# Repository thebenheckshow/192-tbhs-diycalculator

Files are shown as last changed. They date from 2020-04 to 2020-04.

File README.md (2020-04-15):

# 192-tbhs-diycalculator
Ben, Felix and Max take us back to 1972 and the invention of the first calculator this week, then decide to hack their own! Watch as they use the Raspberry Pi Compute Module and a Formlabs SLA 3D printer to create their own graphing calculator.

https://www.element14.com/community/docs/DOC-77309/l/episode-192-ben-hecks-diy-calculator-episode

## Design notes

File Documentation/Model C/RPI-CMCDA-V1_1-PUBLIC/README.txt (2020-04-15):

Copyright (c) 2014 Raspberry Pi (Trading) Ltd. All rights reserved.

Redistribution and use in source and binary forms, with or without 
modification, are permitted provided that the following conditions 
are met:

- Redistributions of source code must retain the above copyright notice,
  this list of conditions and the following disclaimer.

- Redistributions in binary form must reproduce the above copyright
  notice, this list of conditions and the following disclaimer in the 
  documentation and/or other materials provided with the distribution.

- Neither the name of the Raspberry Pi Foundation, nor 
  Raspberry Pi (Trading) Ltd, nor the names of its contributors may be
  used to endorse or promote products derived from this product without
  specific prior written permission.

THIS PRODUCT IS PROVIDED BY THE COPYRIGHT HOLDERS AND CONTRIBUTORS 
"AS IS" AND ANY EXPRESS OR IMPLIED WARRANTIES, INCLUDING, BUT NOT 
LIMITED TO, THE IMPLIED WARRANTIES OF MERCHANTABILITY AND FITNESS FOR A
PARTICULAR PURPOSE ARE DISCLAIMED. IN NO EVENT SHALL
RASPBERRY PI (TRADING) LTD BE LIABLE FOR ANY DIRECT, INDIRECT,
INCIDENTAL, SPECIAL, EXEMPLARY, OR CONSEQUENTIAL DAMAGES (INCLUDING,
BUT NOT LIMITED TO, PROCUREMENT OF SUBSTITUTE GOODS OR SERVICES; LOSS
OF USE, DATA, OR PROFITS; OR BUSINESS INTERRUPTION) HOWEVER CAUSED AND
ON ANY THEORY OF LIABILITY, WHETHER IN CONTRACT, STRICT LIABILITY, OR
TORT (INCLUDING NEGLIGENCE OR OTHERWISE) ARISING IN ANY WAY OUT OF THE
USE OF THIS PRODUCT, EVEN IF ADVISED OF THE POSSIBILITY OF SUCH DAMAGE.

This zip file should contain:
  README.txt (this file)
  RPI-CMCDA-V1_1-PUBLIC.DSN (Cadence OrCAD Schematic)
  RPI-CMCDA-V1_1-PUBLIC.brd (Cadence OrCAD/Allegro PCB file)
  RPI-CMCDA-V1_1-PUBLIC-BOM.xlsx (Bill of Materials)
  RPI-CMCDA-V1_1-PUBLIC-SCHEMATIC.pdf (PDF of schematic)
  /GERBERS (Board gerbers, see README.txt in this directory for further info)

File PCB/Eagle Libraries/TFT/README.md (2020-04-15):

Included parts:
---------------

* 7499210124A - Ethernet Jack / LAN-Transformer WE-RJ45LAN 10/100BaseT PoE
  * Datasheet: http://katalog.we-online.de/pbs/datasheet/7499210124A.pdf
* MFCR531 - Standard ISO/IEC 14443 A/B reader solution
  * Datasheet: http://www.nxp.com/documents/data_sheet/MFRC531.pdf
* MI0283QT-11 - 2.8" LCD Module
  * Datasheet: http://www.watterott.com/media/files_public/qwpedbempo/MI0283QT-11_Datasheet.PDF
* STM809 - Reset circuit
  * Datasheet: http://www.st.com/web/en/resource/technical/document/datasheet/CD00003591.pdf
* TL2575 - 1-A SIMPLE STEP-DOWN SWITCHING VOLTAGE REGULATORS
  * Datasheet: http://www.ti.com/lit/ds/symlink/tl2575-05.pdf
* TSC2046 - Low-Voltage I/O TOUCH SCREEN CONTROLLER
  * Datasheet: http://www.ti.com/lit/ds/symlink/tsc2046.pdf

Warranty
--------

Although these Parts are proven in production, there is no warranty that these libraries will fit to your parts. 
So be careful and always recheck them if you use them in your design.

Licence
-------

<br />This work is licensed under a <a rel="license" href="http://creativecommons.org/licenses/by-sa/4.0/">Creative Commons Attribution-ShareAlike 4.0 International License</a>.

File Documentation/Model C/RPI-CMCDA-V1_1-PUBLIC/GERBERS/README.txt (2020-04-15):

Copyright (c) 2014 Raspberry Pi (Trading) Ltd. All rights reserved.

Redistribution and use in source and binary forms, with or without 
modification, are permitted provided that the following conditions 
are met:

- Redistributions of source code must retain the above copyright notice,
  this list of conditions and the following disclaimer.

- Redistributions in binary form must reproduce the above copyright
  notice, this list of conditions and the following disclaimer in the 
  documentation and/or other materials provided with the distribution.

- Neither the name of the Raspberry Pi Foundation, nor 
  Raspberry Pi (Trading) Ltd, nor the names of its contributors may be
  used to endorse or promote products derived from this product without
  specific prior written permission.

THIS PRODUCT IS PROVIDED BY THE COPYRIGHT HOLDERS AND CONTRIBUTORS 
"AS IS" AND ANY EXPRESS OR IMPLIED WARRANTIES, INCLUDING, BUT NOT 
LIMITED TO, THE IMPLIED WARRANTIES OF MERCHANTABILITY AND FITNESS FOR A
PARTICULAR PURPOSE ARE DISCLAIMED. IN NO EVENT SHALL
RASPBERRY PI (TRADING) LTD BE LIABLE FOR ANY DIRECT, INDIRECT,
INCIDENTAL, SPECIAL, EXEMPLARY, OR CONSEQUENTIAL DAMAGES (INCLUDING,
BUT NOT LIMITED TO, PROCUREMENT OF SUBSTITUTE GOODS OR SERVICES; LOSS
OF USE, DATA, OR PROFITS; OR BUSINESS INTERRUPTION) HOWEVER CAUSED AND
ON ANY THEORY OF LIABILITY, WHETHER IN CONTRACT, STRICT LIABILITY, OR
TORT (INCLUDING NEGLIGENCE OR OTHERWISE) ARISING IN ANY WAY OUT OF THE
USE OF THIS PRODUCT, EVEN IF ADVISED OF THE POSSIBILITY OF SUCH DAMAGE.

Name: Raspberry Pi Compute Module Camera / Display Adaptor
Date: 13/10/2014
Ref : RPI-CMCDA-V1_1-PUBLIC

Files:

  *-DRM.art         Manuf. Notes / Drill / Mechanical
  *-BRD.art         Board Edges
  *-TPM.art         Top Paste Mask
  *-TCL.art         Top Component Legend
  *-TSM.art         Top Solder Mask
  *-Lxx.art         Copper Layers (L01 = top layer)
  *-BSM.art         Bottom Solder Mask
  *-X-Y.drl         NC Drill layers X to Y (PLATED HOLES)
  *-TAS.pdf         Top Assembly Drawing
  *-IPC.ipc         IPC Netlist
  *-PLACE.txt       Component placement locations

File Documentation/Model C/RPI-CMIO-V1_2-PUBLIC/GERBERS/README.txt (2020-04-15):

Copyright (c) 2014 Raspberry Pi (Trading) Ltd. All rights reserved.

Redistribution and use in source and binary forms, with or without 
modification, are permitted provided that the following conditions 
are met:

- Redistributions of source code must retain the above copyright notice,
  this list of conditions and the following disclaimer.

- Redistributions in binary form must reproduce the above copyright
  notice, this list of conditions and the following disclaimer in the 
  documentation and/or other materials provided with the distribution.

- Neither the name of the Raspberry Pi Foundation, nor 
  Raspberry Pi (Trading) Ltd, nor the names of its contributors may be
  used to endorse or promote products derived from this product without
  specific prior written permission.

THIS PRODUCT IS PROVIDED BY THE COPYRIGHT HOLDERS AND CONTRIBUTORS 
"AS IS" AND ANY EXPRESS OR IMPLIED WARRANTIES, INCLUDING, BUT NOT 
LIMITED TO, THE IMPLIED WARRANTIES OF MERCHANTABILITY AND FITNESS FOR A
PARTICULAR PURPOSE ARE DISCLAIMED. IN NO EVENT SHALL
RASPBERRY PI (TRADING) LTD BE LIABLE FOR ANY DIRECT, INDIRECT,
INCIDENTAL, SPECIAL, EXEMPLARY, OR CONSEQUENTIAL DAMAGES (INCLUDING,
BUT NOT LIMITED TO, PROCUREMENT OF SUBSTITUTE GOODS OR SERVICES; LOSS
OF USE, DATA, OR PROFITS; OR BUSINESS INTERRUPTION) HOWEVER CAUSED AND
ON ANY THEORY OF LIABILITY, WHETHER IN CONTRACT, STRICT LIABILITY, OR
TORT (INCLUDING NEGLIGENCE OR OTHERWISE) ARISING IN ANY WAY OUT OF THE
USE OF THIS PRODUCT, EVEN IF ADVISED OF THE POSSIBILITY OF SUCH DAMAGE.

Name : Raspberry Pi Compute Module IO Board - PUBLIC RELEASE version
Date : 13/10/2014
Ref  : RPI-CMIO-V1_2-PUBLIC
Files:
  *-DRM.art     Manuf. Notes / Drill / Mechanical
  *-BRD.art     Board Edges
  *-TPM.art     Top Paste Mask
  *-TCL.art     Top Component Legend
  *-TSM.art     Top Solder Mask
  *-Lxx.art     Copper Layers (L01 = top layer)
  *-BSM.art     Bottom Solder Mask
  *-X-Y.drl     NC Drill layers X to Y (PLATED HOLES)
  *-X-Y-np.drl  NC Drill layers X to Y (NON PLATED HOLES)
  *-X-Y.rou     NC Route layers X to Y (PLATED ROUTES)
  *-TAS.pdf     Top Assembly Drawing
  *-BAS.pdf     Top Assembly Drawing
  *-IPC.ipc     IPC Netlist
  *-PLACE.txt   Component placement locations

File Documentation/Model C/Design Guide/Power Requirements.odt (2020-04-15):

COMPUTE MODULE HARDWARE DESIGN GUIDE

POWERING THE MODULE

The Compute Module has six separate supplies that must be present and powered at all times; you cannot leave any of them unpowered, even if a specific interface or GPIO bank is unused. The six supplies are as follows:

1. VBAT is used to power the BCM2835 processor core. It feeds the SMPS that generates the chip core voltage.

2. 3V3 powers various BCM2835 PHYs, IO and the eMMC Flash.

3. 1V8 powers various BCM2835 PHYs, IO and SDRAM.

4. VDAC powers the composite (TV-out) DAC.

5. GPIO0-27_VREF powers the GPIO 0-27 IO bank.

6. GPIO28-45_VREF powers the GPIO 28-45 IO bank.

GPIO28-45_VREF powers the GPIO 28-45 IO bank.

Supply | Voltage / Voltage Range | Tolerance
VBAT | 2.3-5V [1] | +/- 5%
3V3 | 3.3V | +/- 5%
1V8 | 1.8V | +/- 5%
VDAC | 2.5-2.8V (can connect to 3V3 if unused) | +/- 5%
GPIO0-27_VREF | 1.8-3.3V | +/- 5%
GPIO28-45_VREF | 1.8-3.3V | +/- 5%

[1] Note that the voltage range for best SMPS efficiency is ~3.3-4.3V.

POWER SEQUENCING

Supplies must be synchronised to come up at exactly the same time. Alternatively, they should be staggered so that the highest voltage comes up first, then the remaining voltages in descending order. This is to avoid forward biasing internal (on-chip) diodes between supplies, and causing latch-up.

POWER REQUIREMENTS

Exact power requirements will be heavily dependent upon the individual use case. If an on-chip subsystem is unused, it is usually in a low power state or completely turned off. For instance, if your application does not use 3D graphics then a large part of the core digital logic will never turn on and need power. This is also the case for camera and display interfaces, HDMI, USB interfaces, video encoders and decoders, and so on.

Powerchain design is critical for stable and reliable operation of the Compute Module. We strongly recommend that designers spend time measuring and verifying power requirements for their particular use case and application, as well as paying careful attention to power supply sequencing and maximum supply voltage tolerance.

The following table gives a rough guide to minimum supply requirements. However, the user is responsible for verifying that their powerchain is designed to be sufficient for their application. In some more unusual use cases these minimum requirements may well be too low!

Supply | Minimum Requirement (mA or mW)
VBAT | 2000mW [1]
3V3 | 250mA
1V8 | 250mA
VDAC | 25mA
GPIO0-27_VREF | 50mA [2]
GPIO28-45_VREF | 50mA [2]

[1] Note that VBAT is heavily dependent upon the application. For example, with video encoding, 3D and the camera all running the power requirements can be substantial.

[2] Note that each GPIO bank will only need a few mW if unused; however when in use, the requirements will vary depending on the number of IOs in use and the load on each. The maximum load per GPIO bank must not exceed 50mA.

MODULE BOOTING AND FLASHING THE EMMC

The 4GB eMMC Flash device on the Compute Module is directly connected to the primary BCM2835 SD/eMMC interface. These connections are not accessible on the module pins.

When initially powered on, or after the RUN pin has been held low and then released, the BCM2835 will try to access the eMMC device. It will then look for a file called bootcode.bin on the primary partition (which must be FAT) to start booting the system. If it cannot access the eMMC device or the boot code cannot be found, it will fall back to waiting for boot code to be written to it over USB; in other words, its USB port is in slave mode waiting to accept boot code from a suitable host.

A USB boot tool is available on github which allows a host PC running Linux to write the BCM2835 boot code over USB to the module. That boot code then runs and provides access to the eMMC as a USB mass storage device, which can then be read and written using the host PC. Note that a Raspberry Pi can be used as the host machine.

The Compute Module has a pin called EMMC_DISABLE_N which when shorted to GND will disable the eMMC, forcing BCM2835 to boot from USB. Note that when the eMMC is disabled in this way, it takes a few seconds from powering up for the processor to stop attempting to talk to the eMMC device and fall back to booting from USB.

Note that once booted over USB, BCM2835 needs to re-enable the eMMC device (by releasing EMMC_DISABLE_N) to allow access to it as mass storage. It expects to be able to do this by driving the GPIO47_1V8 pin LOW, which at boot is initially an input with a pull up to 1V8. If an end user wishes to add the ability to access the eMMC over USB in their product, similar circuitry to that used on the Compute Module IO Board to enable/disable the USB boot and eMMC must be used; that is, EMMC_DISABLE_N pulled low via MOSFET(s) and released again by MOSFET, with the gate controlled by GPIO47_1V8. Ensure you use MOSFETs suitable for switching at 1.8V (i.e. use a device with Vt << 1.8V).

For a step by step guide to flashing the eMMC please see: < http://www.raspberrypi.org/documentation/hardware/computemodule/cm-emmc-flashing.md >.

COMPUTE MODULE INTERFACES

GPIOS

Note that the GPIO46_1V8 and GPIO47_1V8 pins are 1.8V IO only and are reserved for special functions (HDMI hot plug detect and boot control respectively). Please don’t use these pins for any other purpose, as the software for the Compute Module will always expect these pins to have these special functions. If they are unused please leave them unconnected.

The remaining GPIOs are available for general use and are split into two banks. GPIO0 to GPIO27 are bank 0 and GPIO28-45 make up bank 1. GPIO0-27_VREF is the power supply for bank 0 and GPIO28-45_VREF is the power supply for bank 1. These supplies can be in the range 1.8V-3.3V. These supplies are not optional; each bank must be powered, even when none of the GPIOs for that bank are used.

All GPIOs except GPIO28, 29, 44 and 45 have weak in-pad pull-ups or pull-downs enabled when the device is powered on. Whether the GPIO is pulled up or down is documented in the BCM2835 peripherals document section 6.2. It is recommended to add off-chip pulls to GPIO28, 29, 44 and 45 to make sure they never float during power on and initial boot.

CSI (MIPI SERIAL CAMERA)

The Compute Module has two MIPI serial camera interfaces (CSI); Interface 0 and Interface 1.

Interface 0 is a 2-lane interface; one clock lane and two data lanes.

Interface 1 is a 4-lane interface; one clock lane and four data lanes.

Note that the Raspberry Pi Model A/B camera connector uses Interface 1, but only in a 2-lane configuration.

The camera interface(s) clock and data pins must be routed as matched length, matched phase 100 ohm differential PCB traces.

DSI (MIPI SERIAL DISPLAY)

The Compute Module has 2 MIPI serial display interfaces (DSI); Interface 0 and Interface 1.

Interface 0 is a 2-lane interface; one clock lane and two data lanes.

Interface 1 is a 4-lane interface; one clock lane and four data lanes.

Note that the Raspberry Pi Model A/B display connector uses Interface 1, but only in a 2-lane configuration.

The display interface(s) clock and data pins must be routed as matched length, matched phase 100 ohm differential PCB traces.

USB OTG

The BCM2835 USB port is On-The-Go (OTG) capable. If using either as a fixed slave or fixed master, please tie the USB_OTGID pin to ground.

The USB port (Pins USB_DP and USB_DM) must be routed as matched-phase 90 ohm differential PCB traces.

Note that the port is capable of being used as a true OTG port, but there is currently no documentation, code or examples for this use case.

HDMI

It is recommended that users follow a similar arrangement to the Compute Module IO Board circuitry for HDMI output.

The HDMI CK_P/N (clock) and D0-D2_P/N (data) pins must each be routed as matched length 100 ohm differential PCB traces. It is also important to make sure that each differential pair is closely phase matched.

Finally, keep HDMI traces well away from other noise sources and as short as possible.

Failure to observe these design rules is likely to result in EMC failure.

COMPOSITE (TVDAC)

The TVDAC pin can be used to output composite video. Please route this signal away from noise sources and use a 75 ohm PCB trace.

Note that the TV DAC is powered from the VDAC supply which must be a clean supply of 2.5-2.8V. It is recommended users generate this supply from 3V3 using a low noise LDO.

If the TVDAC output is not used VDAC can be connected to 3V3, but it must be powered even if the TV-out functionality is unused.

COMPUTE MODULE TEMPERATURE RANGE

The operating temperature range of the module is set by the lowest maximum and highest minimum of any of the components.

The Samsung eMMC and Samsung LPDDR2 are all rated for -25 to +80 degrees Celsius, so the range is -25 to +80. BCM2835 and the analogue switch have a greater range; the ceramic capacitors are specified from -25 to +85.

However, this range is the maximum for the silicon die; therefore, users would have to take into account the heat generated when in use and make sure this does not cause the temperature to exceed 80 degrees Celsius.

The user is responsible for designing and testing their system so that these limits are not exceeded.

COMPUTE MODULE FORM FACTOR

The Compute Module conforms to JEDEC MO-224 mechanical specification for 200 pin DDR2 (1.8V) SODIMM modules. Please note that the pinout of the Compute Module is not the same as a DDR2 SODIMM module; they are not electrically compatible.

The maximum component height on the underside of the Compute Module is 1.2mm.

The maximum component height on the top side of the Compute Module is 1.5mm.

The Compute Module PCB thickness is 1.0mm +/- 10%.

Note that the location and arrangement of components on the Compute Module may change slightly over time due to revisions for cost and manufacturing considerations; however, maximum component heights and PCB thickness will be kept as specified.

http://www.raspberrypi.org/documentation/hardware/computemodule/cm-designguide.md

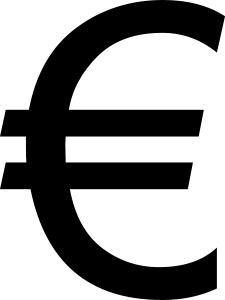
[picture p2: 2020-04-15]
case/225px-Euro_sign.svg.png

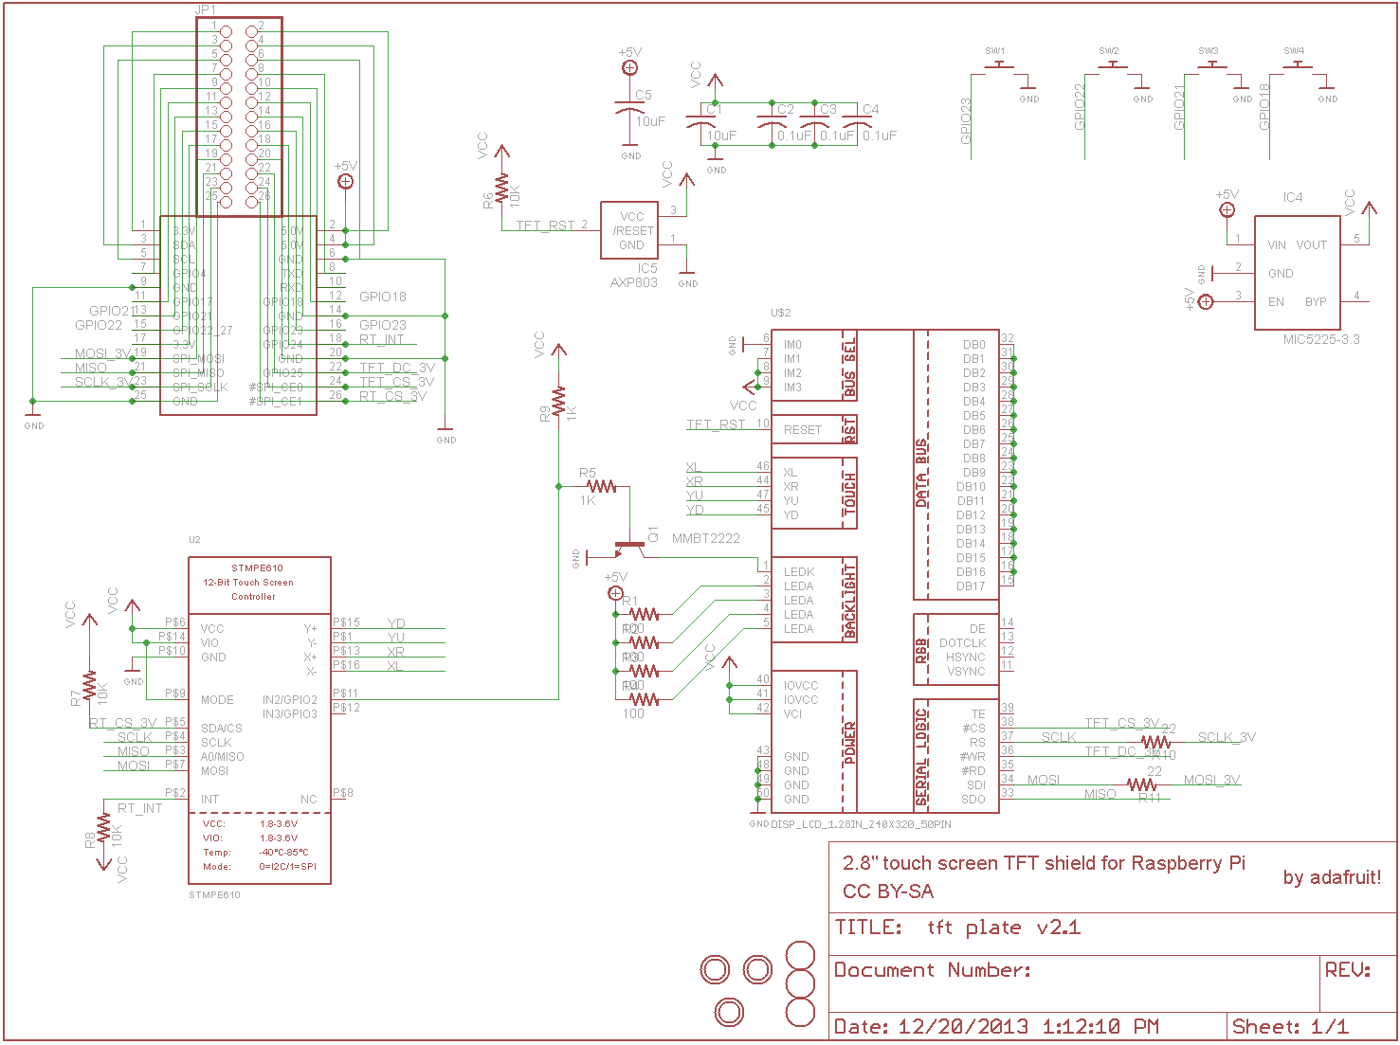
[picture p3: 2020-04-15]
PCB/ComputeCalculator_V2_1_1/References/raspberry_pi_pitftschem.png

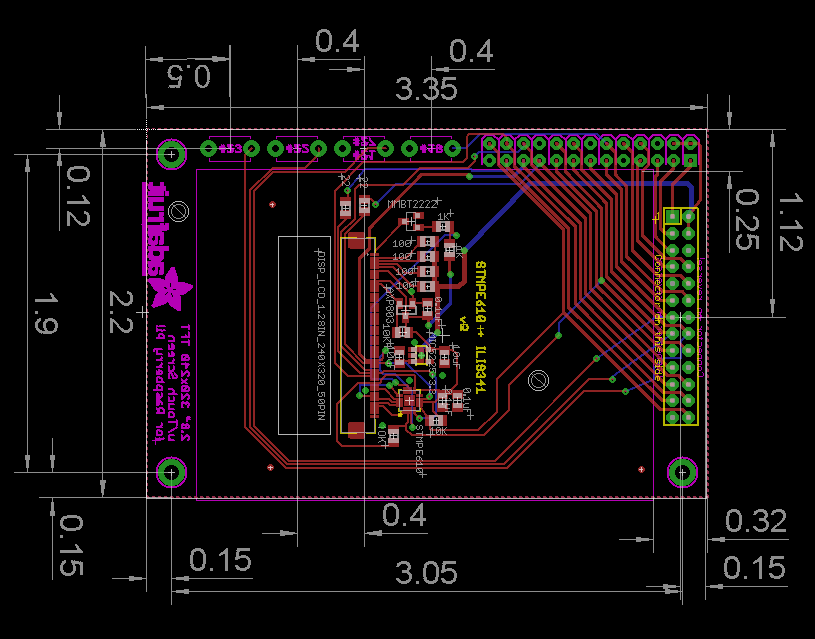
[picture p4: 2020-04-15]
PCB/ComputeCalculator_V2_1_1/References/raspberry_pi_pitftdiagram.png

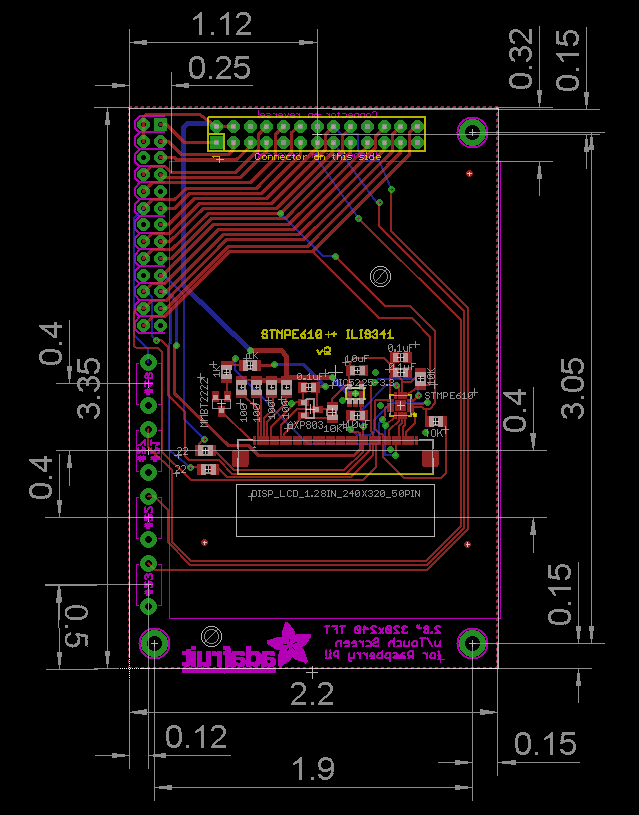
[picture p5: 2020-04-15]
Documentation/Screen/raspberry_pi_pitftdiagram.png

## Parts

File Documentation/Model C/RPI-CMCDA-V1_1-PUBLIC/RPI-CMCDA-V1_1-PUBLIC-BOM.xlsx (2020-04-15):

Item | Quantity | Reference | Part | Manufacturer | Manuf. Part # | Description | Notes
1 | 2 | J1,J3 | 54548-2271 | Molex | 54548-2271 | Connector FFC 0.5mm 22W Bottom Contact
2 | 2 | J2,J4 | SFW15R-2STE1LF | FCI | SFW15R-2STE1LF | Connector FFC 1.0mm 15W Top Contact
3 | 2 | FFC1,FFC2 | 687 622 050 002 | Wurth Electronics | 687 622 050 002 | FFC Flexi, 22W, 0.5mm, 50mm, 0.3mm thick, Contacts on same side | Alternate part from Toby Electronics is FFC5-22-A-42-8-4-50
1 | 1 | PCB | RPI-CMCDA-V1_1 PCB |  |  | Printed Circuit Board

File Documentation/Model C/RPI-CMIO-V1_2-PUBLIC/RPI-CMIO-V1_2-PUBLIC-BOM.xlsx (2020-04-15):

Item | Quantity | Reference | Part | Voltage | Current | Power | Material | Size | Tolerance | Manufacturer | Manuf. Part No | Description
1 | 4 | C7,C8,C11,C12 | 10u | 6.3V |  |  | X7R | 2012 | 20% | Generic | Generic | CAP, CHIP, 2012, 10u, 20%, 6.3V
2 | 6 | C2,C19,C20,C1,C3,C10 | 47u | 6.3V |  |  | X7R | 3216 | 20% | Generic | Generic | CAP, CHIP, 3216, 47u, 20%, 6.3V
3 | 3 | C4,C13,C14 | 1u | 6.3V |  |  | X7R | 1005 | 10% | Generic | Generic | CAP, CHIP, 1005, 1u, 10%, 6.3V
4 | 1 | C5 | 4.7u | 6.3V |  |  | X7R | 1608 | 20% | Generic | Generic | CAP, CHIP, 1608, 4.7u, 20%, 6.3V
5 | 5 | C6,C9,C15,C16,C17 | 100n | 6.3V |  |  | X7R | 1005 | 10% | Generic | Generic | CAP, CHIP, 1005, 100n, 10%, 6.3V
6 | 2 | C21,C22 | NO FIT |  |  |  |  | 1005 |  | Generic | Generic | CAP, CHIP, 1005
7 | 1 | D1 | RED |  |  |  |  | 1608 |  | Generic | Generic | LED, SMT, 1608, RED
8 | 1 | D2 | GREEN |  |  |  |  | 1608 |  | Generic | Generic | LED, SMT, 1608, GREEN
9 | 1 | F1 | MF-MSMF200 | 6V | 2.0A |  |  |  |  | Bourns | MF-MSMF200 | Polyfuse, 2.0A hold, 4.0A trip
10 | 1 | J1 | DDR2 SODIMM |  |  |  |  |  |  | TE | 1473005-4 | DDR2 SODIMM Socket
11 | 2 | J2,J15 | 10103594-0001LF |  |  |  |  |  |  | FCI | 10103594-0001LF | Socket, uUSB, B, RA, PTH/SMT
12 | 1 | J4 | 3W 0.1" PIN HDR |  |  |  |  |  |  | Generic | Generic | 3W 0.1" pin header single row
13 | 2 | J5,J6 | 60W 0.1" PIN HDR |  |  |  |  |  |  | Generic | Generic | 60W 0.1" pin header (2 rows x30)
14 | 1 | J7 | NO FIT |  |  |  |  |  |  | Generic | Generic | 10W 2.5MM Keyed Box Header
15 | 4 | J9,J10,J11,J12 | 54548-2271 |  |  |  |  |  |  | Molex | 54548-2271 | 0.5MM FFC 22W RA BC
16 | 1 | J13 | 47151-1051 |  |  |  |  |  |  | Molex | 47151-1051 | HDMI Con, RA, SMT with PTH lugs
17 | 1 | J14 | 61400416021 |  |  |  |  |  |  | Wurth | 61400416021 | USB A Standard Single PTH RA
18 | 2 | L1,L2 | 4.7u |  | 2A |  |  | 4x4mm | 20% | Bourns | SRN4018-4R7M | Semi shielded power inductor, 4.7uH, Isat=2A, Irma=1.9A, R=84mR
19 | 5 | Q1,Q2,Q3,Q4,Q5 | DMG1012T |  |  |  |  |  |  | Diodes Inc | DMG1012T | MOSFET, N, LOW VT, LOGIC
20 | 7 | R1,R4,R5,R6,R7,R8,R19 | 0R |  |  | 0.1W |  | 2012 | 1% | Generic | Generic | RES, CHIP, 2012, 1%, 0.25W 0R
21 | 6 | R2,R18,R26,R27,R28,R29 | 100K |  |  | 63mW |  | 1005 | 1% | Generic | Generic | RES, CHIP, 1005, 100K, 1%, 0.063W
22 | 2 | R3,R9 | 470R |  |  | 63mW |  | 1005 | 1% | Generic | Generic | RES, CHIP, 1005, 470R, 1%, 0.063W
23 | 4 | R10,R20,R21,R30 | 47K |  |  | 63mW |  | 1005 | 1% | Generic | Generic | RES, CHIP, 1005, 47K, 1%, 0.063W
24 | 2 | R11,R12 | 1K |  |  | 63mW |  | 1005 | 1% | Generic | Generic | RES, CHIP, 1005, 1K, 1%, 0.063W
25 | 4 | R13,R14,R16,R17 | 1.8K |  |  | 63mW |  | 1005 | 1% | Generic | Generic | RES, CHIP, 1005, 1.8K, 1%, 0.063W
26 | 1 | R15 | 27K |  |  | 63mW |  | 1005 | 1% | Generic | Generic | RES, CHIP, 1005, 27K, 1%, 0.063W
27 | 1 | R22 | 0R |  |  |  |  | 1005 |  | Generic | Generic | RES, CHIP, 1005, 0R
28 | 1 | R23 | 0R |  |  |  |  | 1005 |  | Generic | Generic | RES, CHIP, 1005, 0R
29 | 1 | U1 | PAM2306AYPKE |  |  |  |  |  |  | Diodes | PAM2306AYPKE | IC, SMT, Dual SMPS, V1=3V3, V2=1V8
30 | 1 | U2 | AP7115-25SEG |  |  |  |  | SOT323 |  | Diodes Inc | AP7115-25SEG-7 | IC, LDO, 2.5V, 150mA SOT-25
31 | 1 | U3 | AP2331W |  |  |  |  |  |  | Diodes | AP2331W | Current limited load switch, 200mA
32 | 1 | U4 | ESD5384 |  |  |  |  |  |  | ON Semiconductor | ESD5384 | IC, ESD, HDMI CONTROL
33 | 2 | U5 | FSUSB42UMX |  |  |  |  |  |  | Fairchild | FSUSB42UMX | USB 2.0 SWITCH
34 | 2 | R24,R25 | NO FIT |  |  |  |  |  |  | Generic | Generic | RES, CHIP, 1005
35 | 1 | J3 | 6W 0.1" PIN HDR |  |  |  |  |  |  | Generic | Generic | 2x3W 0.1" pin header (2 rows x3)
36 | 3 | SHUNT/JUMPER |  |  |  |  |  |  |  | Generic | Generic | 2x shunt fitted to J3 (3V3) and J4 (EN)
37 | 1 | RPI-CMIO-V1_2 PCB |  |  |  |  |  |  |  |  |  | Printed Circuit Board

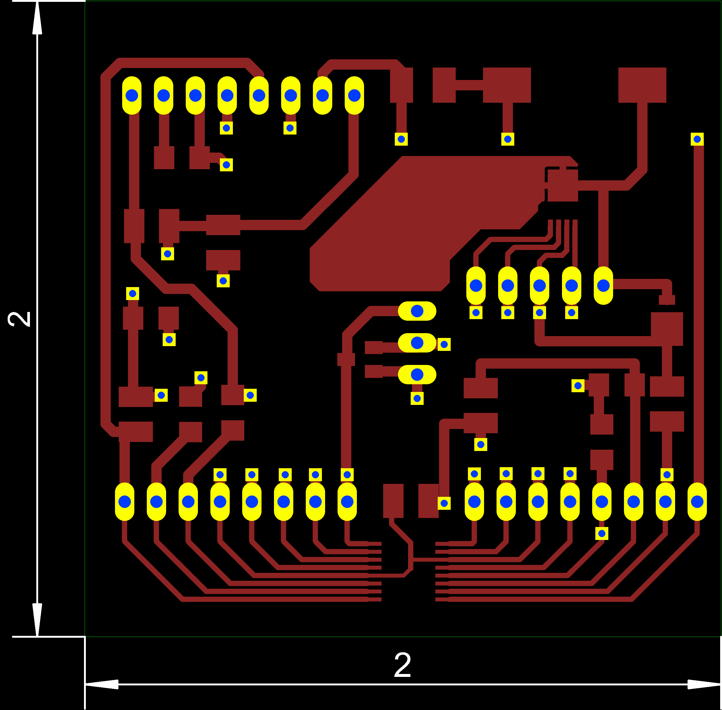
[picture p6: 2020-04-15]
Components/Charge Controller/v4/Etch Mask/EtchMask-gimp.jpg

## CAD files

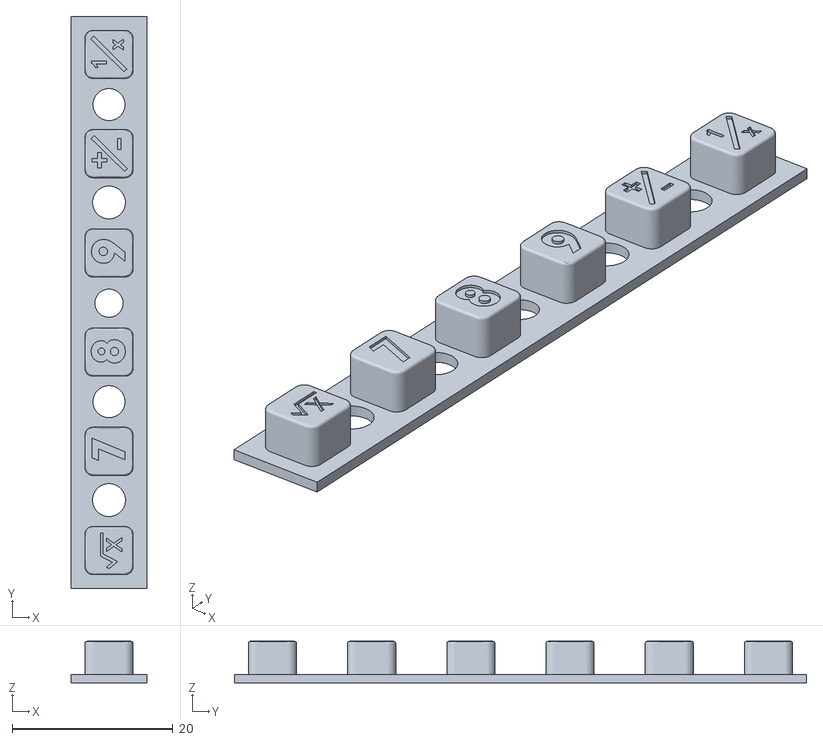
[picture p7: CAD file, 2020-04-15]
case/STL/row7.stl
9.43 x 71.1 x 5.16

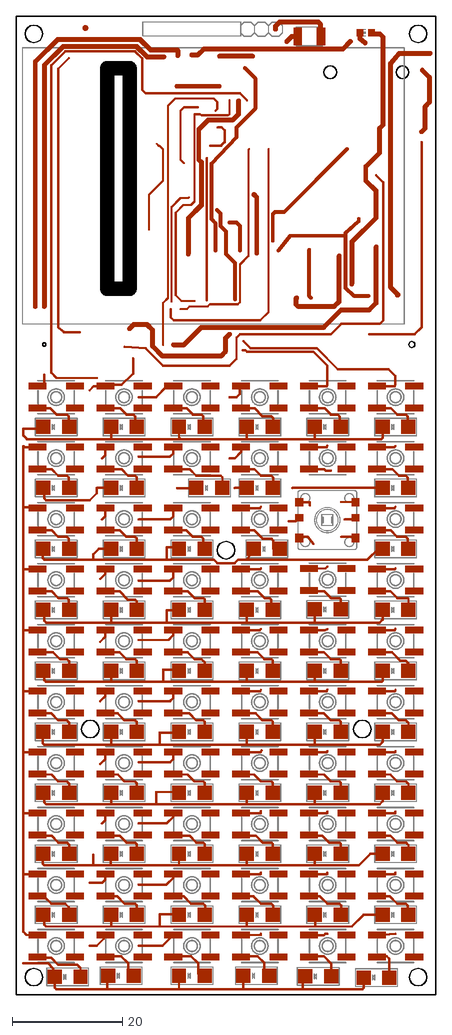
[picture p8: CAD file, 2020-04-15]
PCB/ComputeCalculator_V2_1_1/Design/ComputeCalculator.dxf
76.2 x 177.8

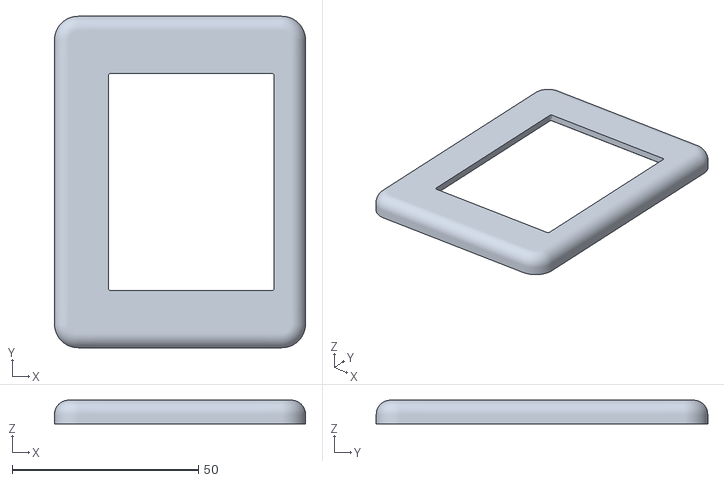
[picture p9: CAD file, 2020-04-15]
case/STL/screen_frame_2.stl
67.3 x 88.9 x 6.35

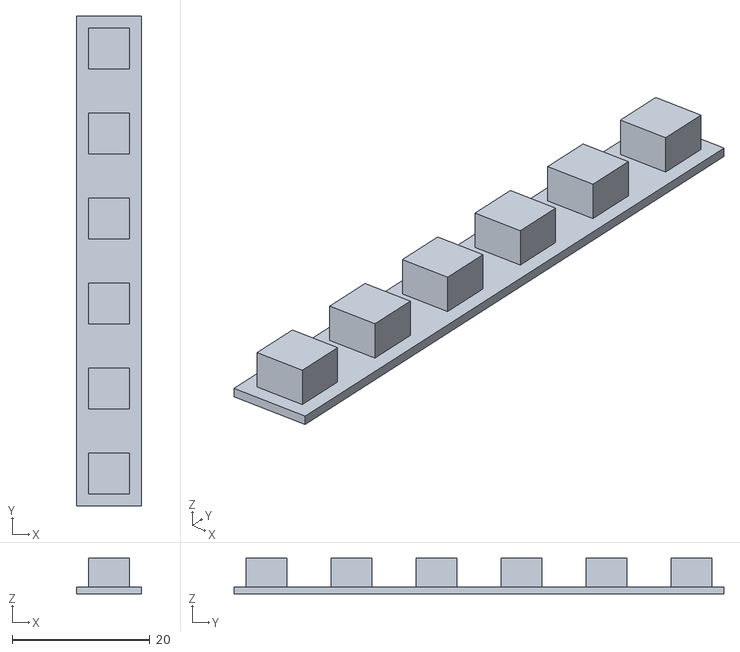
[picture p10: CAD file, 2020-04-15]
case/STL/button strip 2.stl
9.43 x 71.1 x 5.16

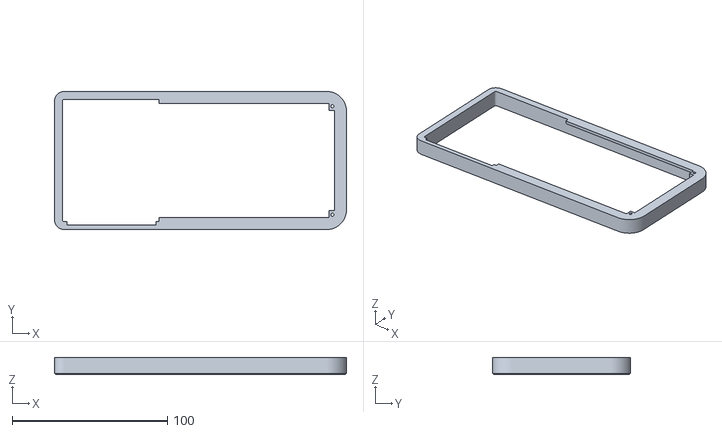
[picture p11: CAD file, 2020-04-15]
case/STL/case front.stl
188.0 x 88.9 x 11.1

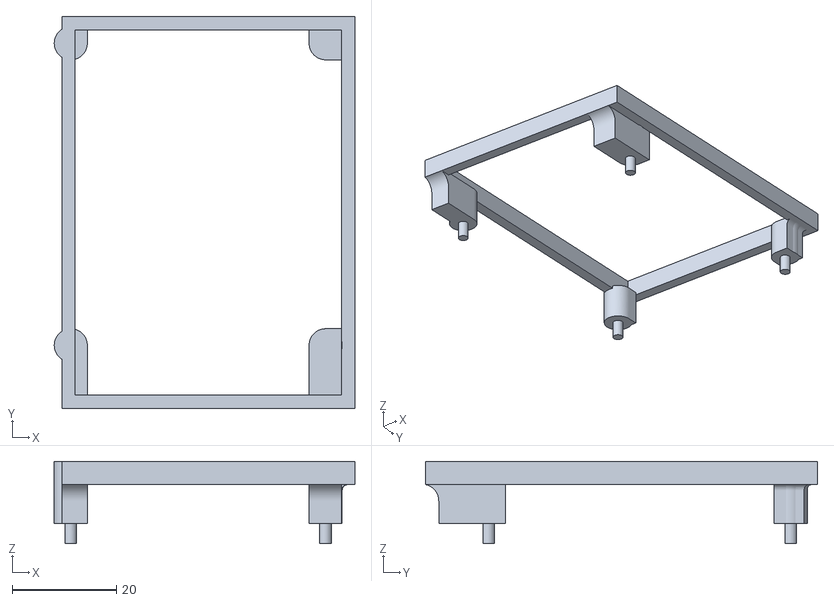
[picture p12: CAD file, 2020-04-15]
case/STL/LCD to Pi frame.stl
57.6 x 75.1 x 15.7

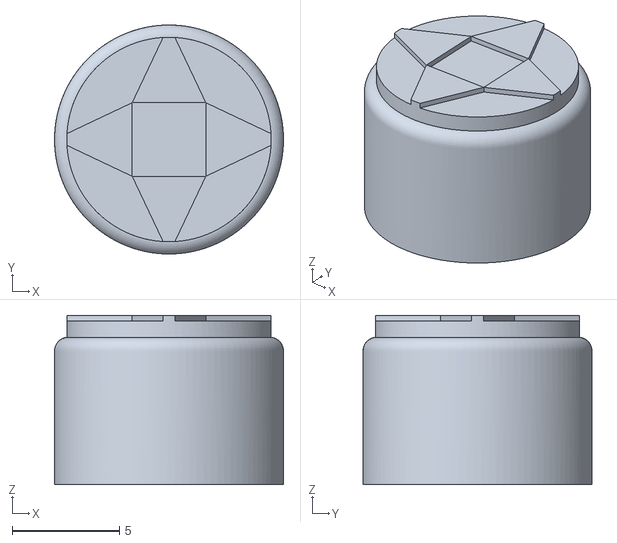
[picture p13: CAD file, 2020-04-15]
case/STL/d-pad.stl
10.7 x 10.7 x 7.87

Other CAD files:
case/STL/row3.stl
case/STL/row6.stl
case/STL/row2.stl
case/STL/row5.stl
case/STL/button strip.stl
case/STL/row4.stl
case/STL/row9.stl
case/STL/row8.stl

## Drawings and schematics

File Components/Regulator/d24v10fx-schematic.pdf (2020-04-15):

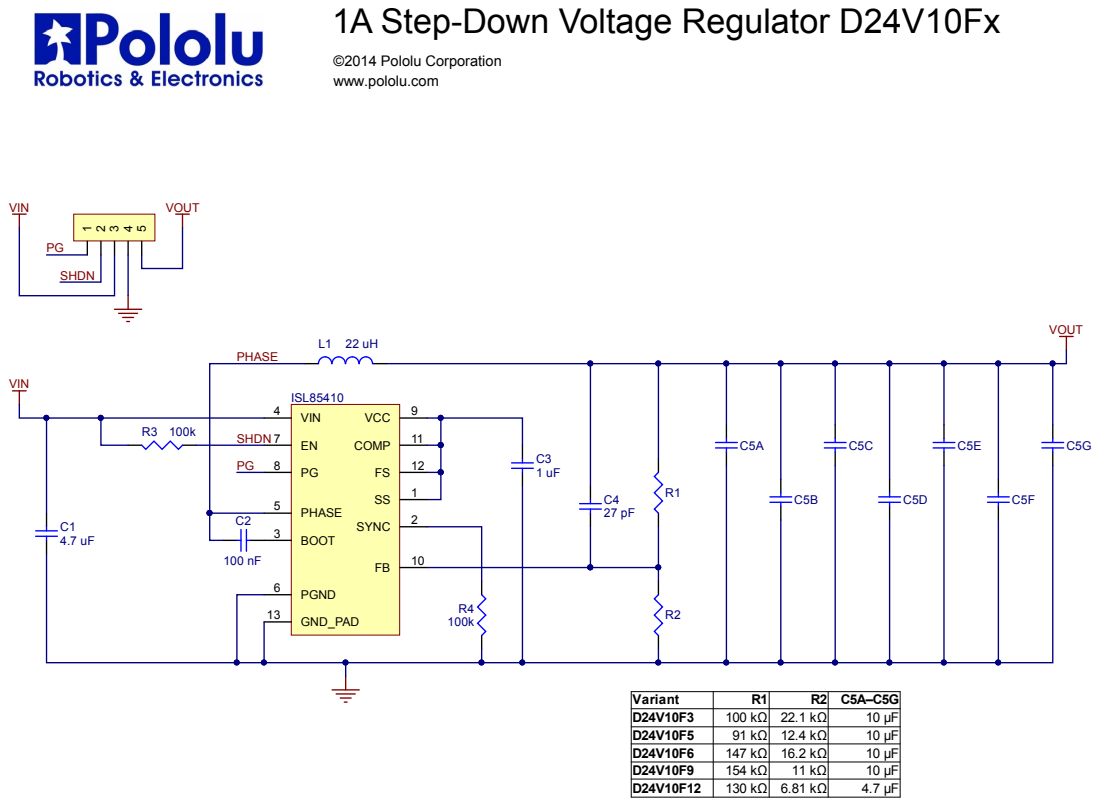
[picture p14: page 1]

1A Step-Down Voltage Regulator D24V10Fx

Variant | R1 | R2 | C5A–C5G
D24V10F3 | 100 kΩ | 22.1 kΩ | 10 μF
D24V10F5 | 91 kΩ | 12.4 kΩ | 10 μF
D24V10F6 | 147 kΩ | 16.2 kΩ | 10 μF
D24V10F9 | 154 kΩ | 11 kΩ | 10 μF
D24V10F12 | 130 kΩ | 6.81 kΩ | 4.7 μF

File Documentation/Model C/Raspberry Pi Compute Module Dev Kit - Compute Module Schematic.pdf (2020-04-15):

5

4

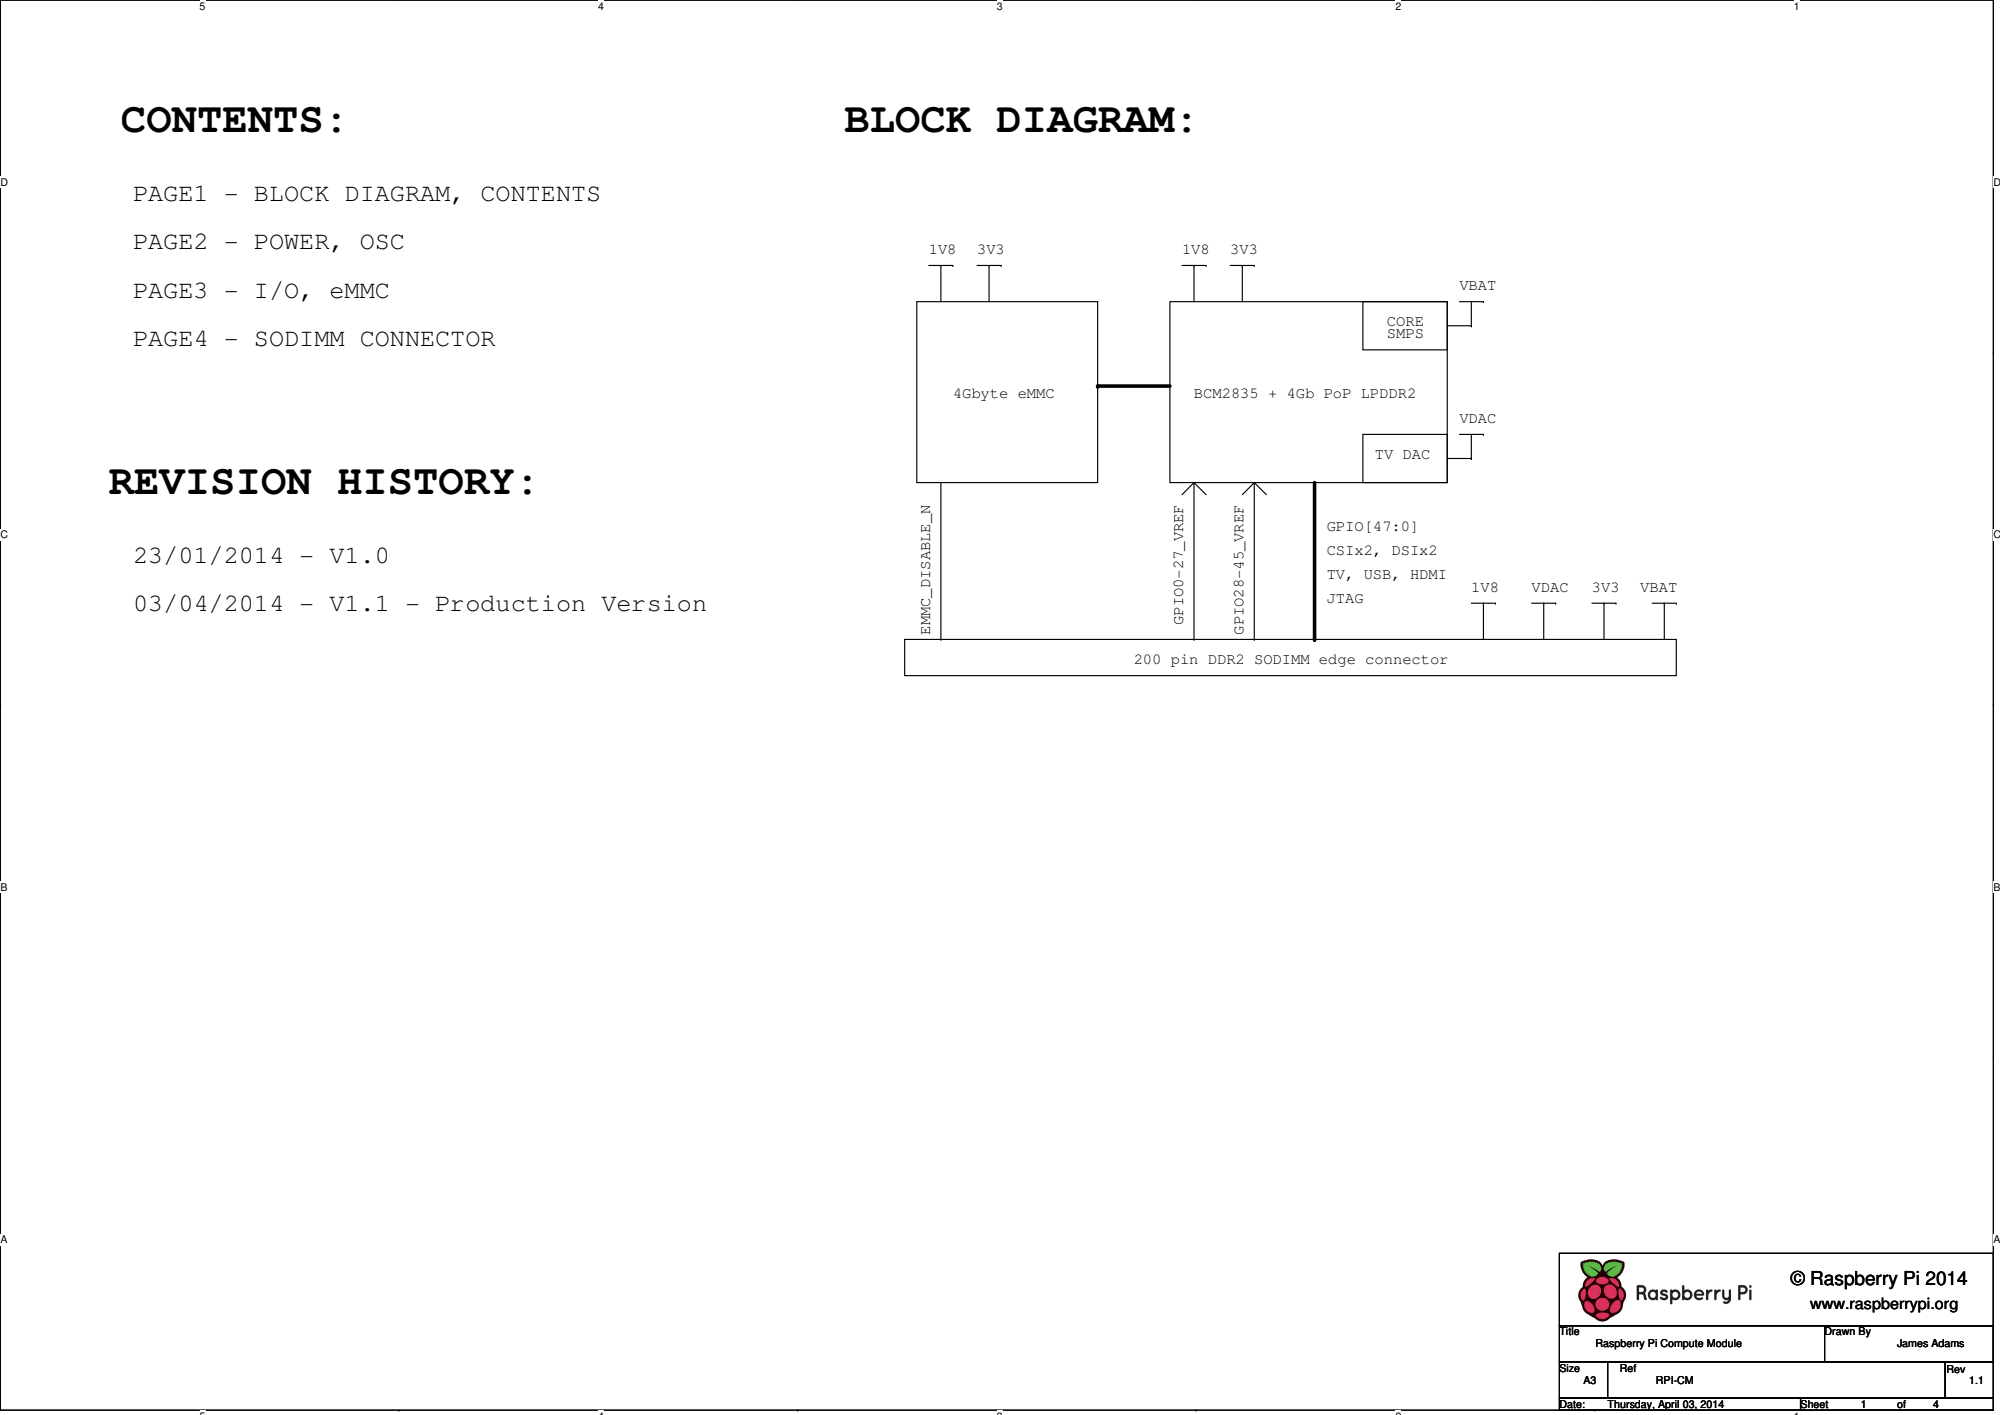
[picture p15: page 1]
BCM2835 + 4Gb PoP LPDDR2; CORE SMPS; 4Gbyte eMMC; VBAT; GPIO0-27_VREF; EMMC_DISABLE_N; PAGE2 - POWER, OSC; PAGE3 - I/O, eMMC; PAGE4 - SODIMM CONNECTOR; TV DAC; VDAC; CONTENTS:; BLOCK DIAGRAM:; REVISION HISTORY:; 03/04/2014 - V1.1 - Production Version; Title; Size; Ref; Rev; Date:; Sheet; Drawn By; James Adams; RPI-CM; Thursday, April 03, 2014; © Raspberry Pi 2014

PAGE1 - BLOCK DIAGRAM, CONTENTS

GPIO28-45_VREF GPIO[47:0] CSIx2, DSIx2 TV, USB, HDMI JTAG

200 pin DDR2 SODIMM edge connector

© Raspberry Pi 2014
www.raspberrypi.org

Raspberry Pi Compute Module

D D

## XTAL_N

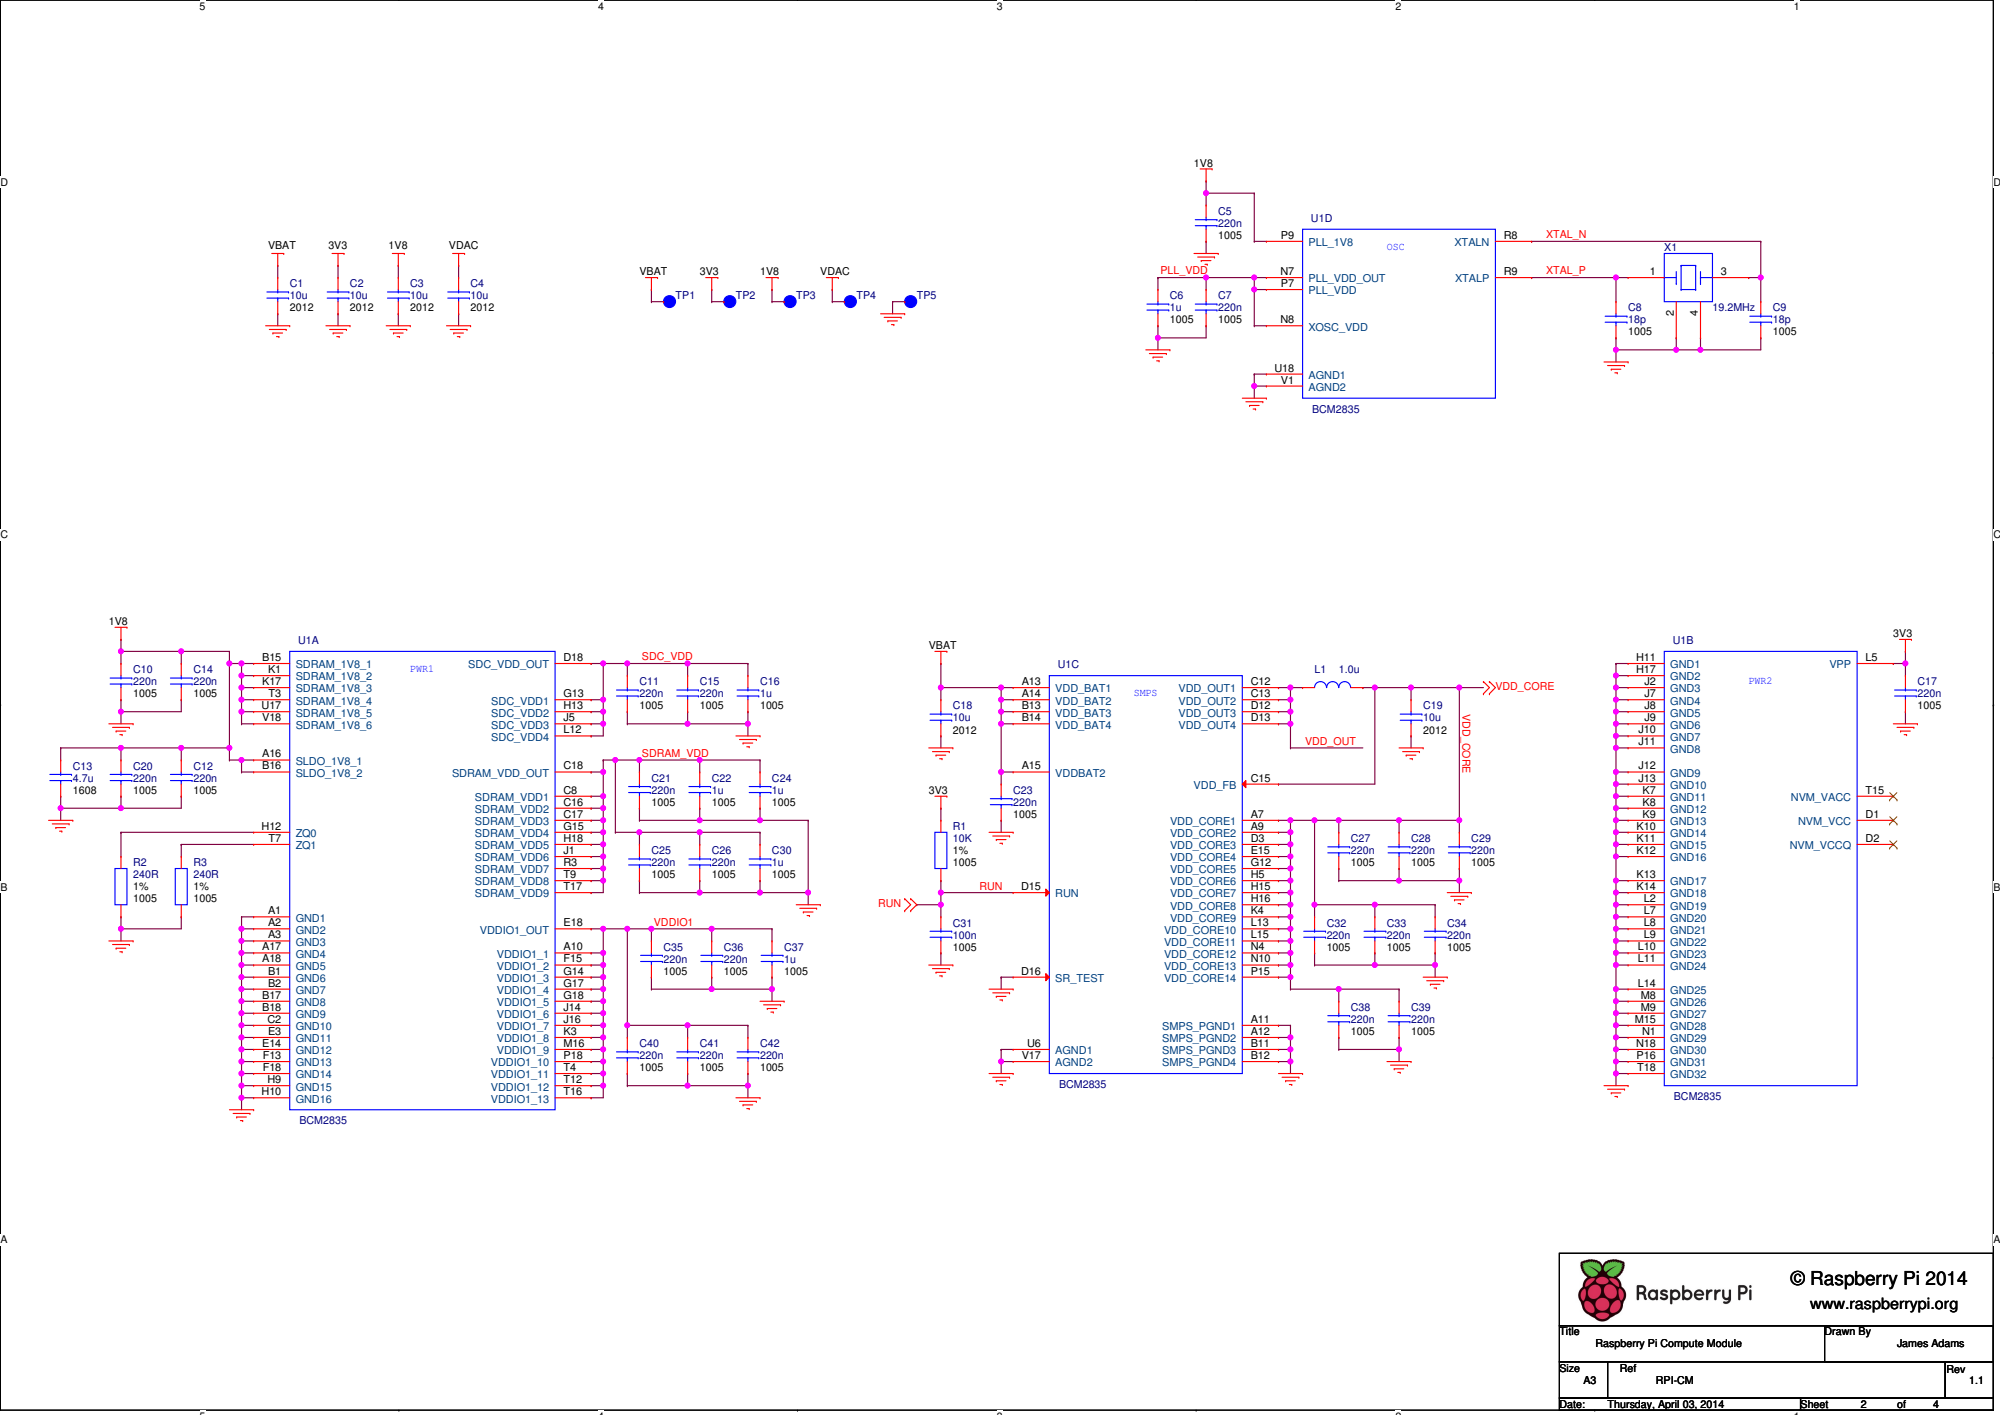
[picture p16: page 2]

D D

## Route bold-ringed signals as matched

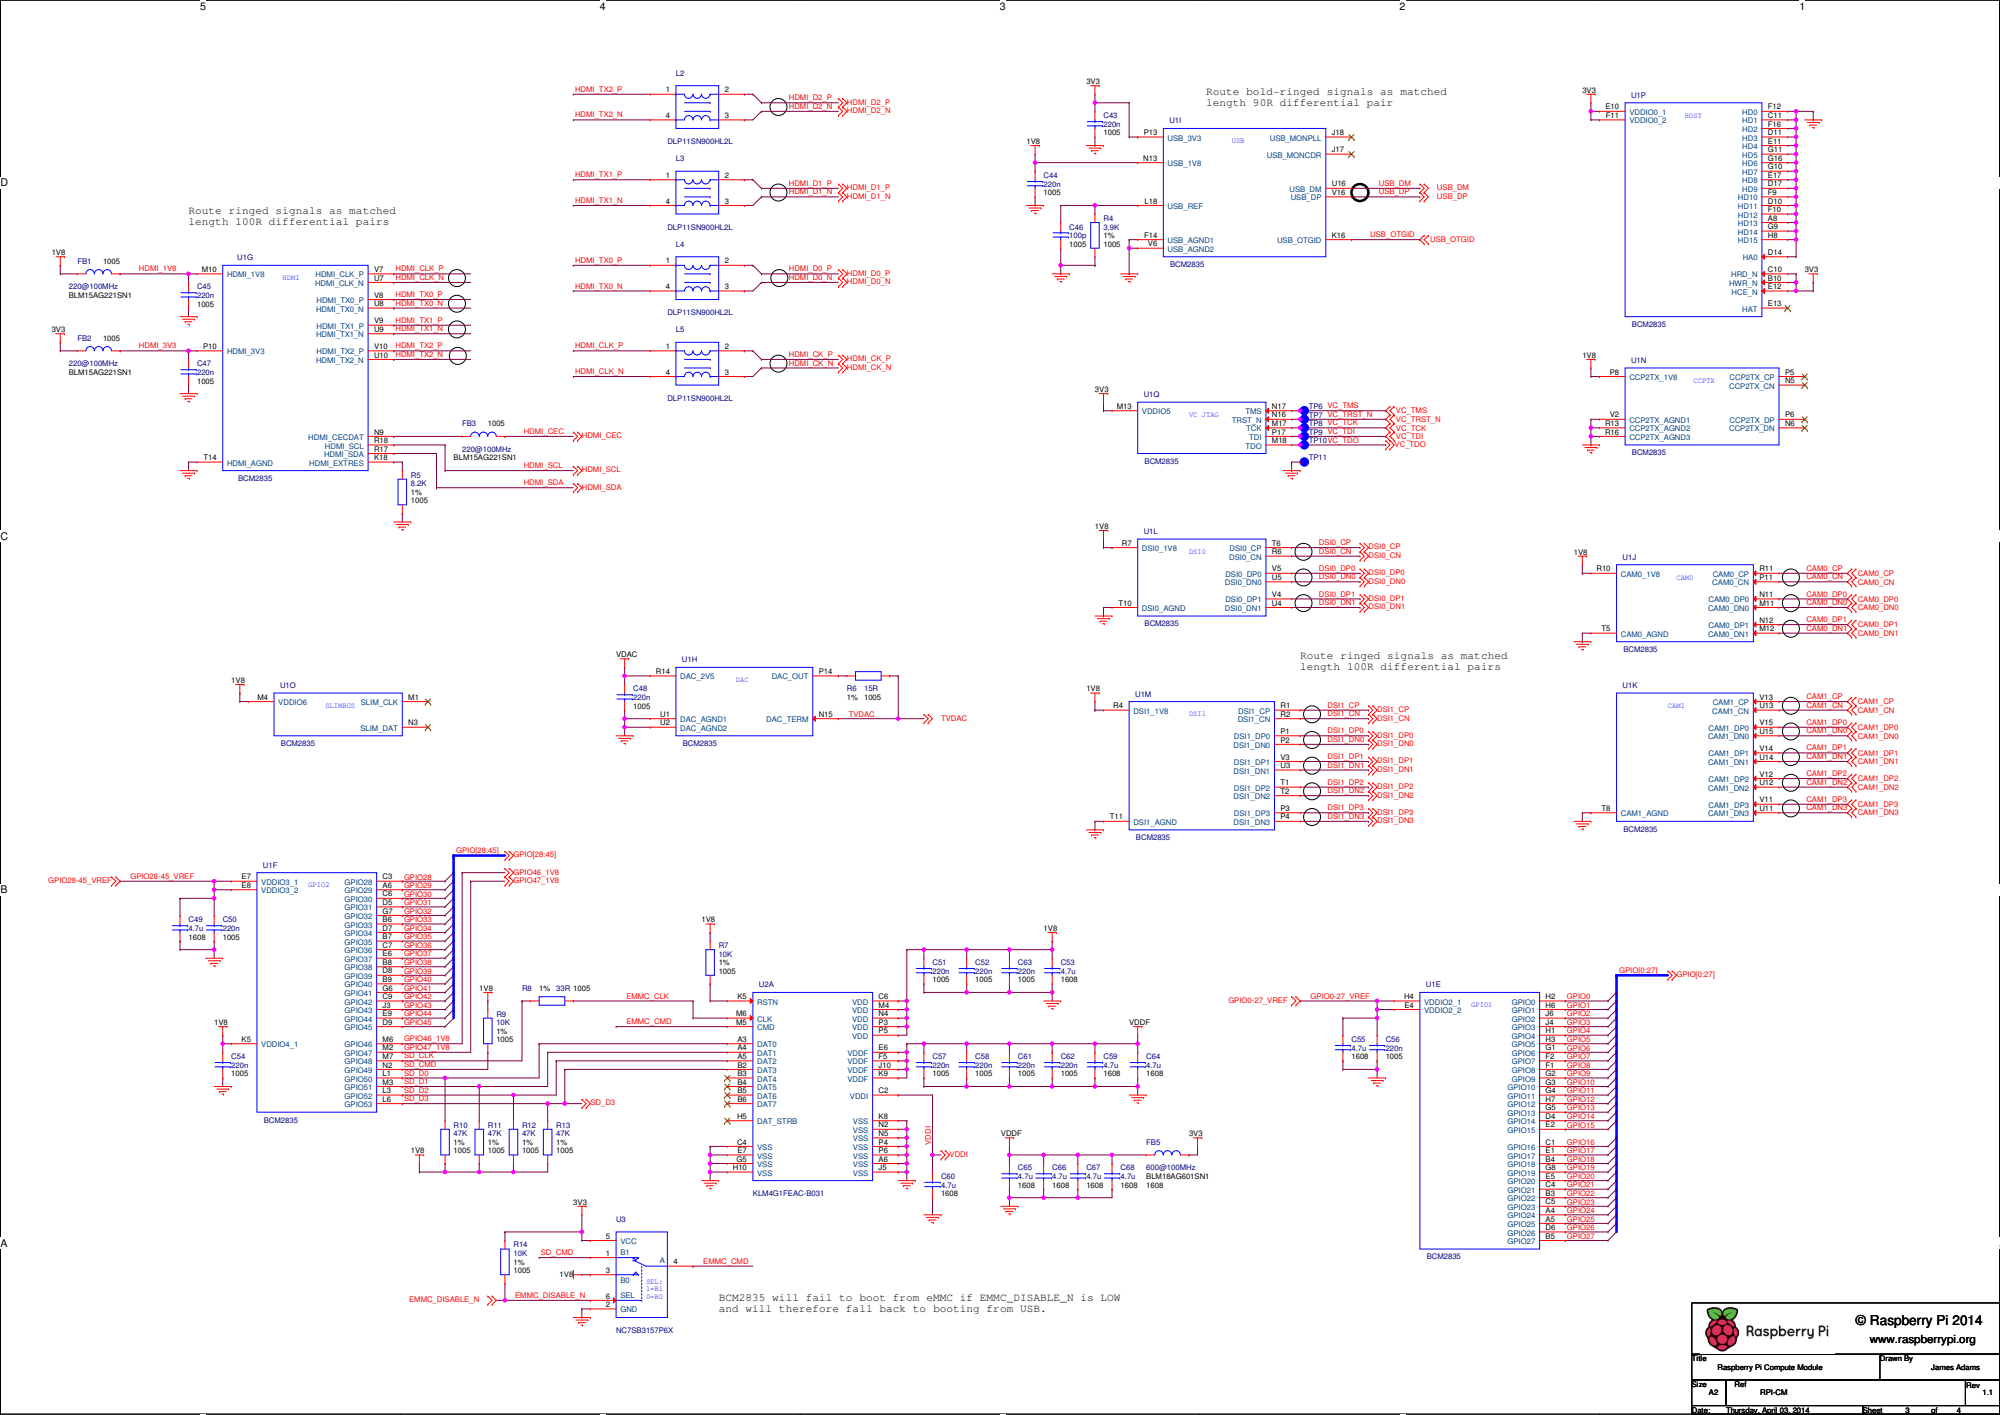
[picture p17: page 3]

Route ringed signals as matched
length 100R differential pairs

BCM2835 will fail to boot from eMMC if EMMC_DISABLE_N is LOW
and will therefore fall back to booting from USB.

D

D

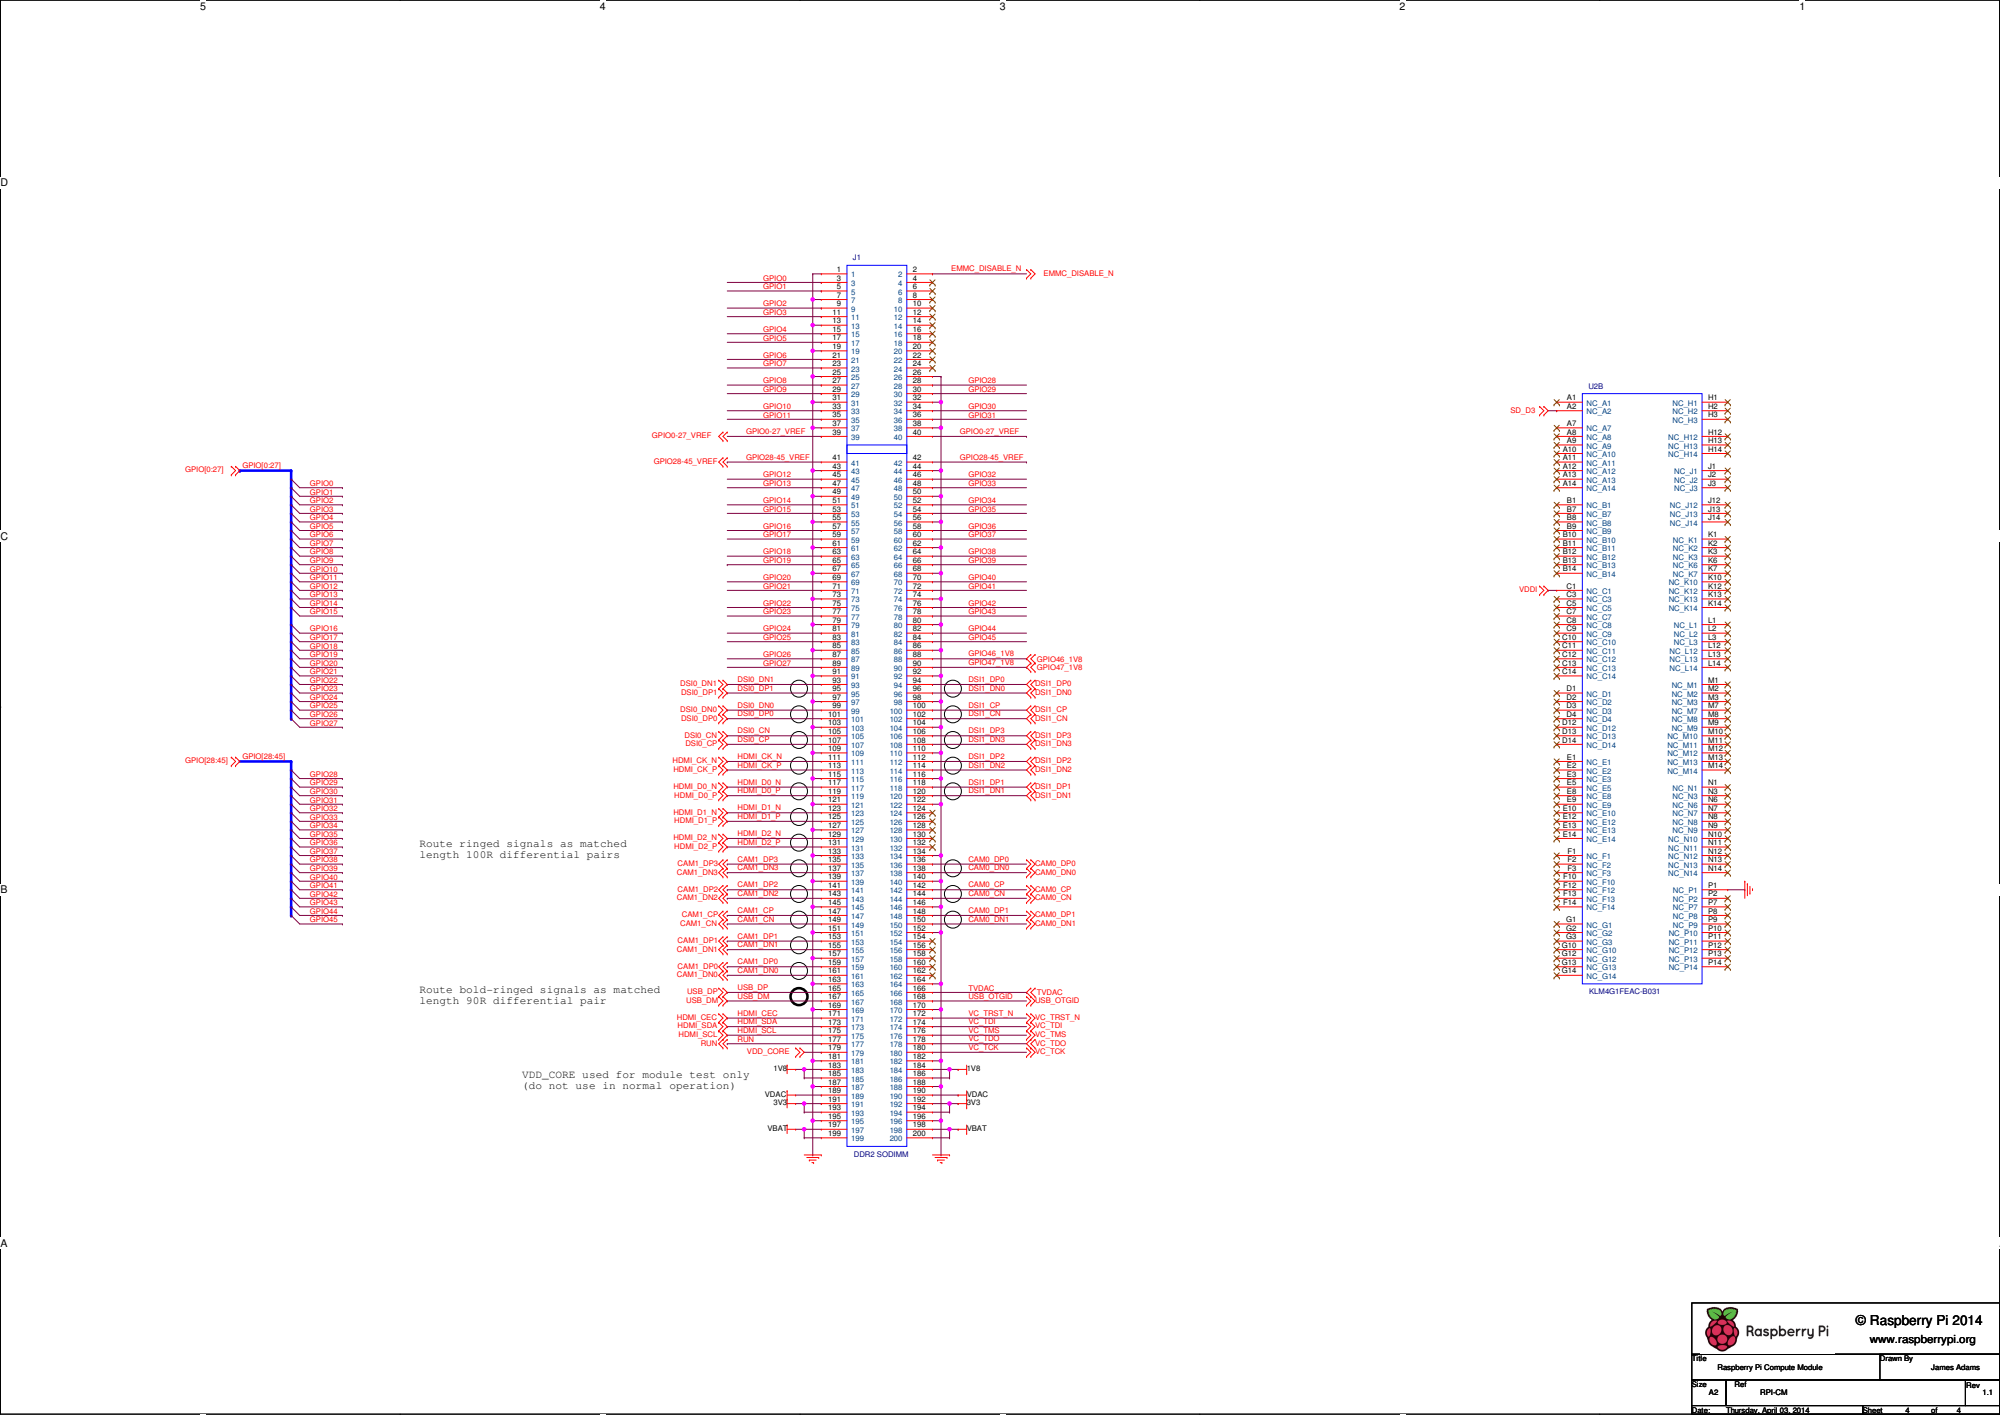
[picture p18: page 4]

Route ringed signals as matched
length 100R differential pairs

Route bold-ringed signals as matched
length 90R differential pair

VDD_CORE used for module test only
(do not use in normal operation)

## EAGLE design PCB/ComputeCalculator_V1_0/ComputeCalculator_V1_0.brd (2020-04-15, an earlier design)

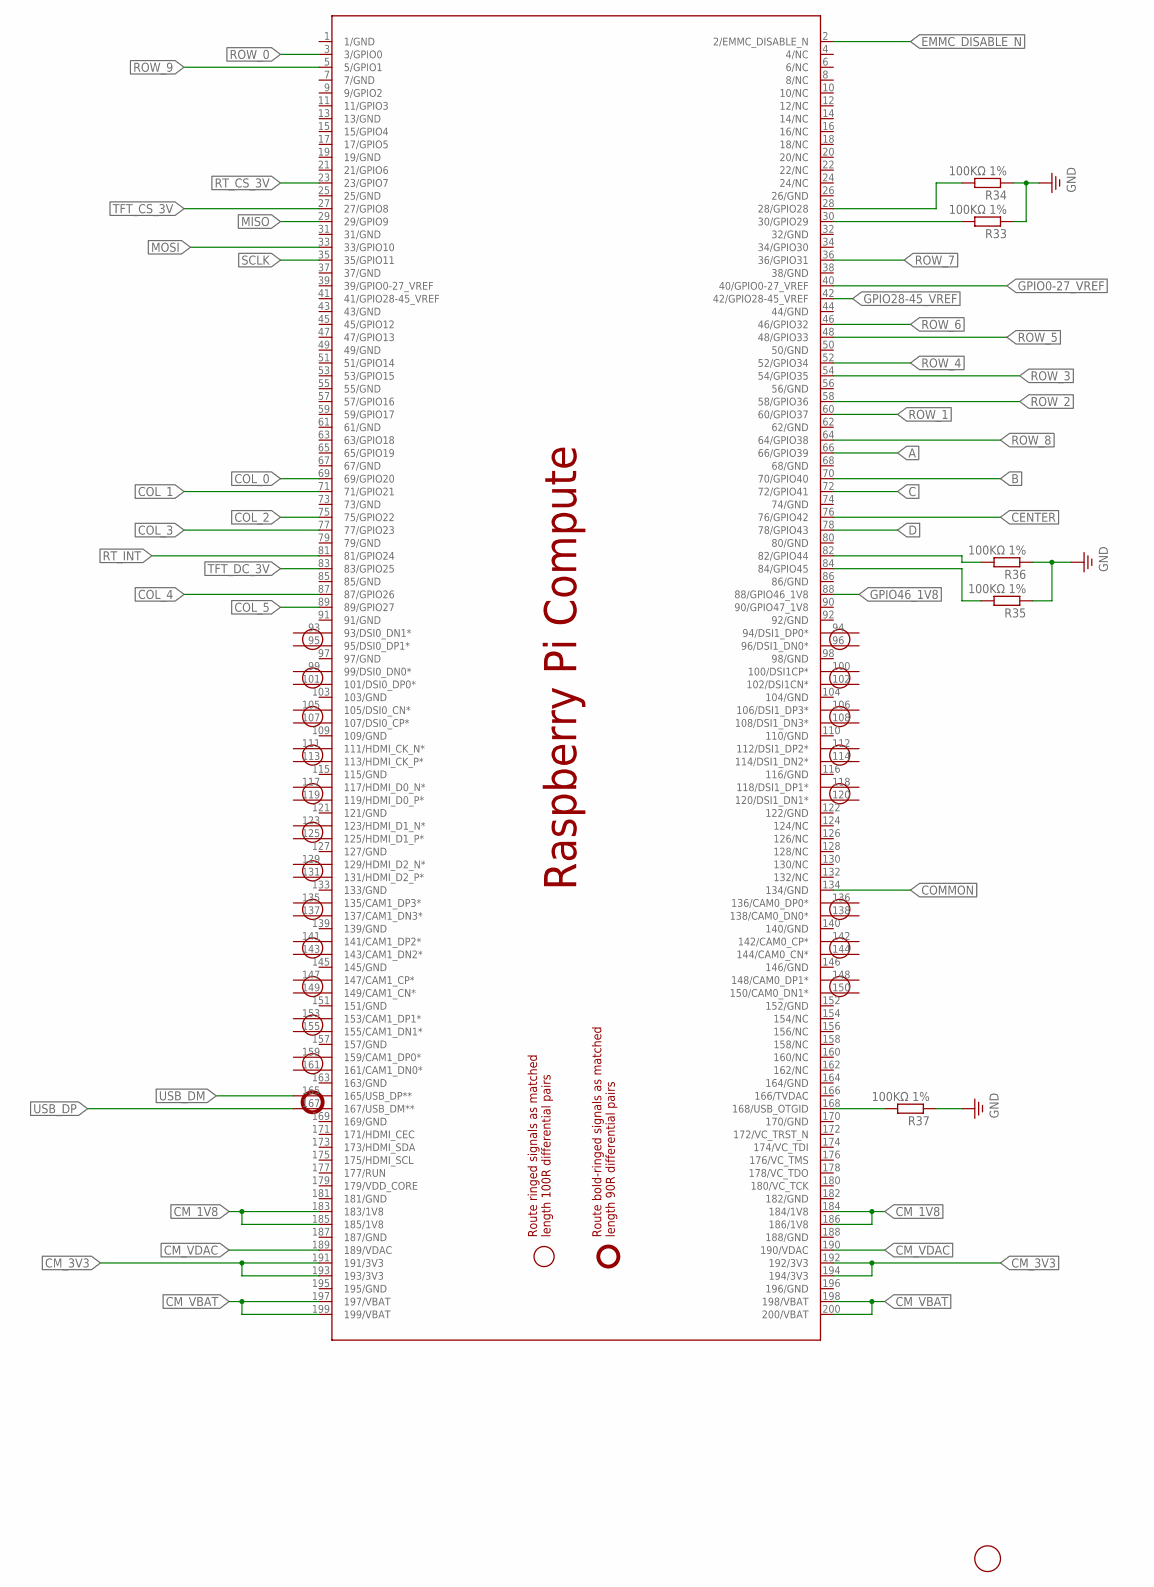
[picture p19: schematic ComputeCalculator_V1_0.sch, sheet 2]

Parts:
PCB1: RPI_COMPUTE
R33, R34, R35, R36, R37: 100KΩ 1%; M1206
U$2: FIDUCIAL; FIDUCIAL_1MM

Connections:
A: PCB1.66 (66/GPIO39); also elsewhere on the board
B: PCB1.70 (70/GPIO40); also elsewhere on the board
C: PCB1.72 (72/GPIO41); also elsewhere on the board
CENTER: PCB1.76 (76/GPIO42); also elsewhere on the board
CM_1V8: PCB1.183 (183/1V8), PCB1.184 (184/1V8), PCB1.185 (185/1V8), PCB1.186 (186/1V8); also elsewhere on the board
CM_3V3: PCB1.191 (191/3V3), PCB1.192 (192/3V3), PCB1.193 (193/3V3), PCB1.194 (194/3V3); also elsewhere on the board
CM_VBAT: PCB1.197 (197/VBAT), PCB1.198 (198/VBAT), PCB1.199 (199/VBAT), PCB1.200 (200/VBAT); also elsewhere on the board
CM_VDAC: PCB1.189 (189/VDAC), PCB1.190 (190/VDAC); also elsewhere on the board
COL_0: PCB1.69 (69/GPIO20); also elsewhere on the board
COL_1: PCB1.71 (71/GPIO21); also elsewhere on the board
COL_2: PCB1.75 (75/GPIO22); also elsewhere on the board
COL_3: PCB1.77 (77/GPIO23); also elsewhere on the board
COL_4: PCB1.87 (87/GPIO26); also elsewhere on the board
COL_5: PCB1.89 (89/GPIO27); also elsewhere on the board
COMMON: PCB1.134 (134/GND); also elsewhere on the board
D: PCB1.78 (78/GPIO43); also elsewhere on the board
EMMC_DISABLE_N: PCB1.2 (2/EMMC_DISABLE_N)
GND: R33.1, R34.1, R35.1, R36.1, R37.1; also elsewhere on the board
GPIO0-27_VREF: PCB1.40 (40/GPIO0-27_VREF); also elsewhere on the board
GPIO28-45_VREF: PCB1.42 (42/GPIO28-45_VREF); also elsewhere on the board
GPIO46_1V8: PCB1.88 (88/GPIO46_1V8)
MISO: PCB1.29 (29/GPIO9); also elsewhere on the board
MOSI: PCB1.33 (33/GPIO10); also elsewhere on the board
unnamed: PCB1.28 (28/GPIO28), R34.2
unnamed: PCB1.82 (82/GPIO44), R36.2
unnamed: PCB1.84 (84/GPIO45), R35.2
unnamed: PCB1.168 (168/USB_OTGID), R37.2
unnamed: PCB1.30 (30/GPIO29), R33.2
ROW_0: PCB1.3 (3/GPIO0); also elsewhere on the board
ROW_1: PCB1.60 (60/GPIO37); also elsewhere on the board
ROW_2: PCB1.58 (58/GPIO36); also elsewhere on the board
ROW_3: PCB1.54 (54/GPIO35); also elsewhere on the board
ROW_4: PCB1.52 (52/GPIO34); also elsewhere on the board
ROW_5: PCB1.48 (48/GPIO33); also elsewhere on the board
ROW_6: PCB1.46 (46/GPIO32); also elsewhere on the board
ROW_7: PCB1.36 (36/GPIO31); also elsewhere on the board
ROW_8: PCB1.64 (64/GPIO38); also elsewhere on the board
ROW_9: PCB1.5 (5/GPIO1); also elsewhere on the board
RT_CS_3V: PCB1.23 (23/GPIO7); also elsewhere on the board
RT_INT: PCB1.81 (81/GPIO24); also elsewhere on the board
SCLK: PCB1.35 (35/GPIO11); also elsewhere on the board
TFT_CS_3V: PCB1.27 (27/GPIO8); also elsewhere on the board
TFT_DC_3V: PCB1.83 (83/GPIO25); also elsewhere on the board
USB_DM: PCB1.165 (165/USB_DP**); also elsewhere on the board
USB_DP: PCB1.167 (167/USB_DM**); also elsewhere on the board

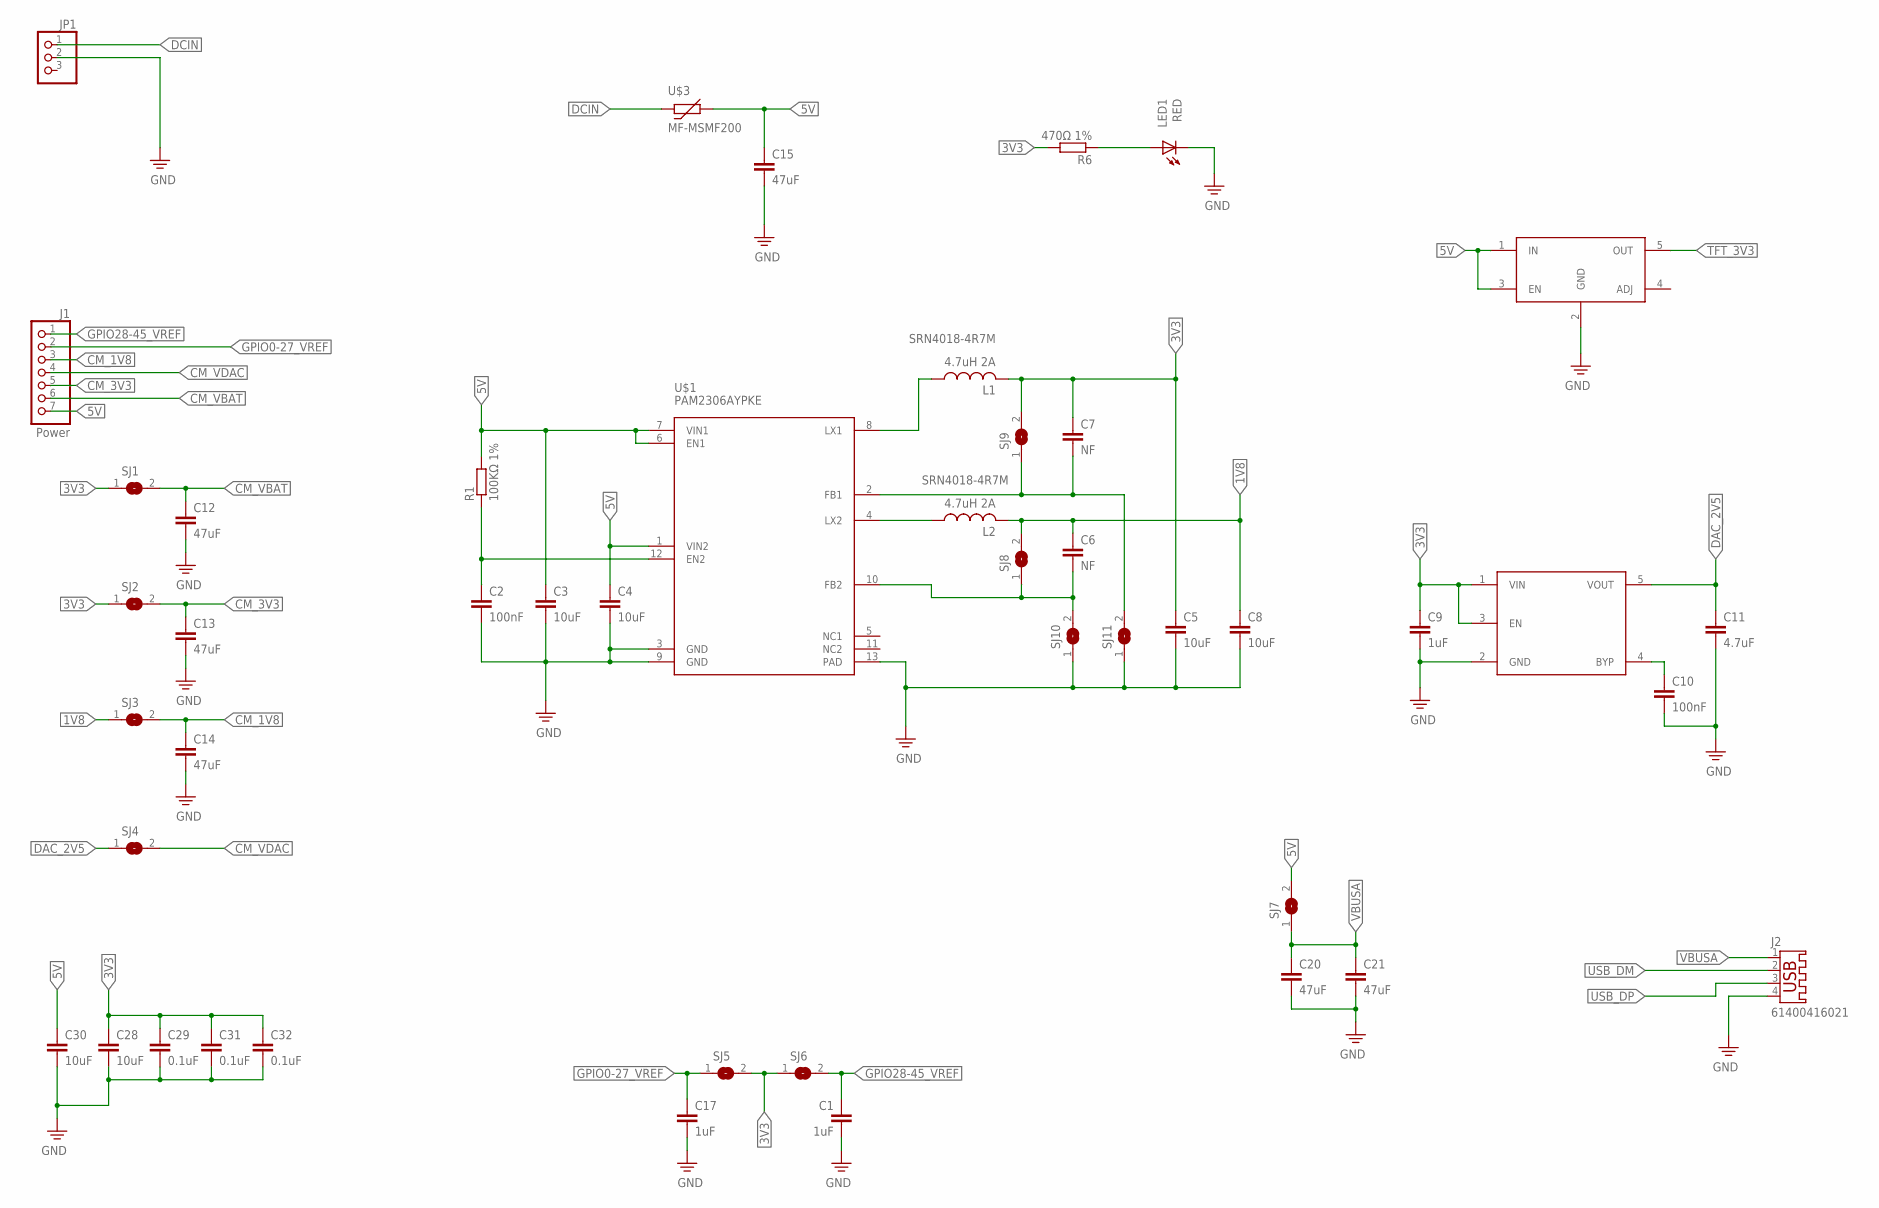
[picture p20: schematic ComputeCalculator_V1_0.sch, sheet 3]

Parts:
C1, C9, C17: 1uF; C1206
C2, C10: 100nF; C1206
C3, C4, C5, C8, C28, C30: 10uF; C1206
C6, C7: NF; C1206
C11: 4.7uF; C1206
C12, C13, C14, C20, C21: 47uF; C1206
C15: 47uF; C0603
C29, C31, C32: 0.1uF; C1206
J1: Power; 1X7-BIG
J2: 61400416021; USB-A003
JP1: PINHD-1X3; 1X03
L1, L2: SRN4018-4R7M; POWER-CHOKE_WE-TPC
LED1: RED; CHIP-LED0805
R1: 100KΩ 1%; M1206
R6: 470Ω 1%; M1206
SJ1, SJ2, SJ3, SJ4, SJ5, SJ6, SJ7, SJ8, SJ9, SJ10, SJ11: JUMPER; SJW
U$1: PAM2306AYPKE; WDFN_12L
U$3: MF-MSMF200
U$4: AP7115-25SEG; SOT-25
U$5: MIC5225; SOT-25

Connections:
1V8: C6.1, C8.1, L2.2, SJ3.1, SJ8.2
3V3: C5.1, C7.1, C9.1, C28.1, C29.1, C31.1, C32.1, L1.2, R6.2, SJ1.1, SJ2.1, SJ5.2, SJ6.1, SJ9.2, U$4.1 (VIN), U$4.3 (EN)
5V: C3.1, C4.1, C15.1, C30.1, J1.7, R1.2, SJ7.2, U$1.1 (VIN2), U$1.6 (EN1), U$1.7 (VIN1), U$3.P$2 (2), U$5.1 (IN), U$5.3 (EN)
CM_1V8: C14.1, J1.3, SJ3.2; also elsewhere on the board
CM_3V3: C13.1, J1.5, SJ2.2; also elsewhere on the board
CM_VBAT: C12.1, J1.6, SJ1.2; also elsewhere on the board
CM_VDAC: J1.4, SJ4.2; also elsewhere on the board
DAC_2V5: C11.1, SJ4.1, U$4.5 (VOUT)
DCIN: JP1.1, U$3.P$1 (1)
GND: C1.2, C2.2, C3.2, C4.2, C5.2, C8.2, C9.2, C10.2, C11.2, C12.2, C13.2, C14.2, C15.2, C17.2, C20.2, C21.2, C28.2, C29.2, C30.2, C31.2, C32.2, J2.4, JP1.2, LED1.C, SJ10.1, SJ11.1, U$1.3 (GND), U$1.9 (GND), U$1.13 (PAD), U$4.2 (GND), U$5.2 (GND); also elsewhere on the board
GPIO0-27_VREF: C17.1, J1.2, SJ5.1; also elsewhere on the board
GPIO28-45_VREF: C1.1, J1.1, SJ6.2; also elsewhere on the board
unnamed: C7.2, SJ9.1, SJ11.2, U$1.2 (FB1)
unnamed: LED1.A, R6.1
unnamed: C2.1, R1.1, U$1.12 (EN2)
unnamed: C6.2, SJ8.1, SJ10.2, U$1.10 (FB2)
unnamed: L1.1, U$1.8 (LX1)
unnamed: L2.1, U$1.4 (LX2)
unnamed: C10.1, U$4.4 (BYP)
TFT_3V3: U$5.5 (OUT); also elsewhere on the board
USB_DM: J2.2; also elsewhere on the board
USB_DP: J2.3; also elsewhere on the board
VBUSA: C20.1, C21.1, J2.1, SJ7.1

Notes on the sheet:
4.7uH 2A

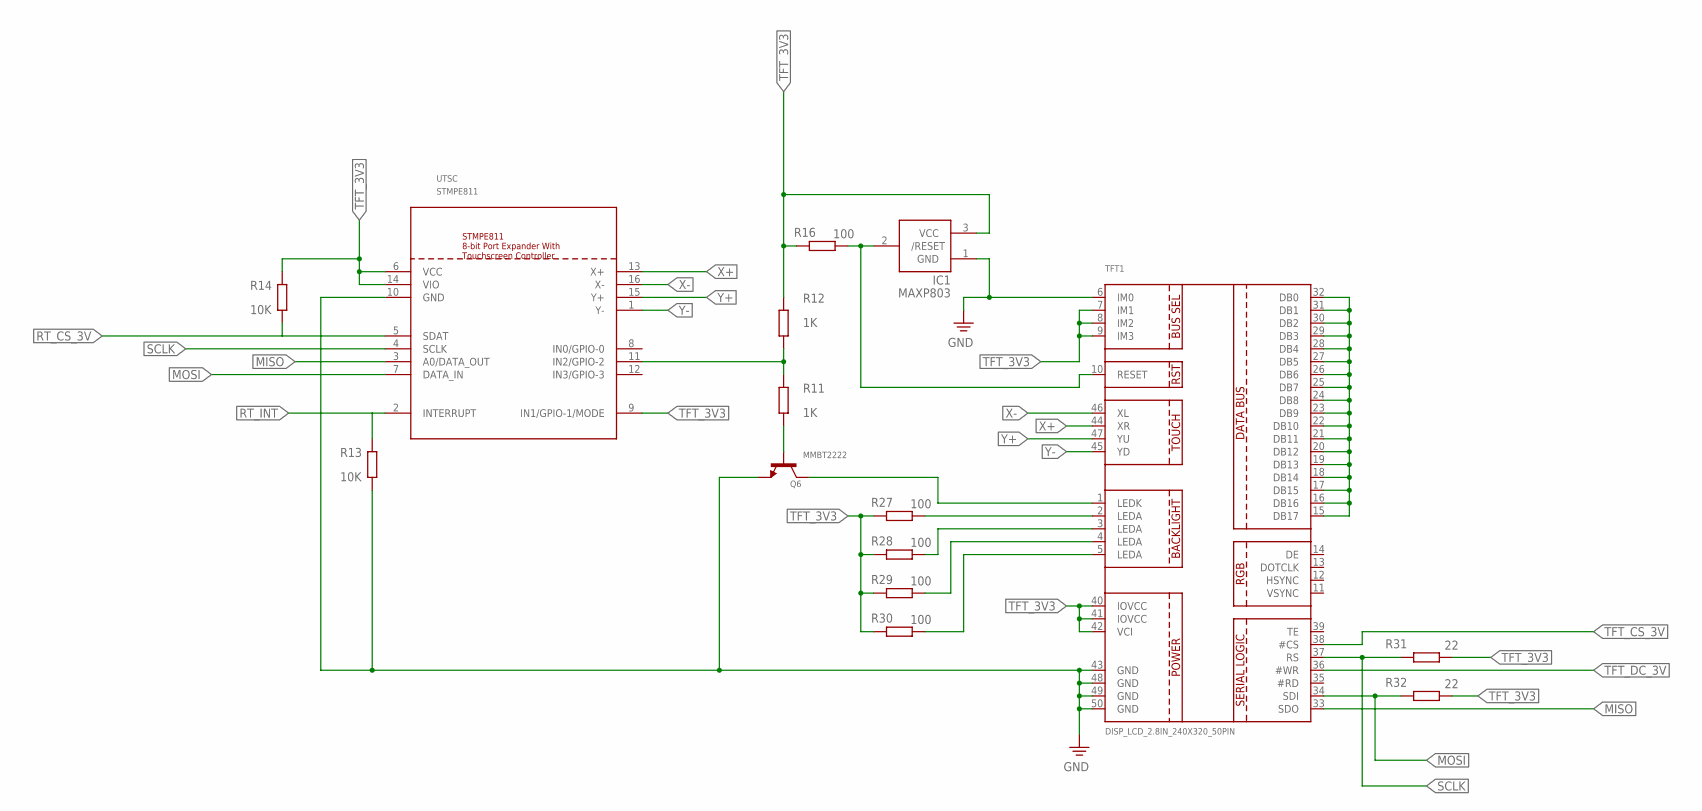
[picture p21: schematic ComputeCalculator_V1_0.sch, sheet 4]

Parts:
IC1: MAXP803; SOT23
Q6: MMBT2222; SOT23-WIDE
R11, R12: 1K; M1206
R13, R14: 10K; M1206
R16, R27, R28, R29, R30: 100; M1206
R31, R32: 22; M1206
TFT1: DISP_LCD_2.8IN_240X320_50PIN; TFT_2.83IN_240X320_50PIN
UTSC: STMPE811; QFN16L

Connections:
GND: IC1.1 (GND), Q6.2 (E), R13.2, TFT1.6 (IM0), TFT1.43 (GND), TFT1.48 (GND), TFT1.49 (GND), TFT1.50 (GND), UTSC.10 (GND); also elsewhere on the board
MISO: TFT1.33 (SDO), UTSC.3 (A0/DATA_OUT); also elsewhere on the board
MOSI: R32.2, TFT1.34 (SDI), UTSC.7 (DATA_IN); also elsewhere on the board
unnamed: Q6.3 (C), TFT1.1 (LEDK)
unnamed: R11.1, R12.2, UTSC.11 (IN2/GPIO-2)
unnamed: Q6.1 (B), R11.2
unnamed: R27.1, TFT1.2 (LEDA)
unnamed: R28.1, TFT1.3 (LEDA)
unnamed: R29.1, TFT1.4 (LEDA)
unnamed: R30.1, TFT1.5 (LEDA)
unnamed: TFT1.15 (DB17), TFT1.16 (DB16), TFT1.17 (DB15), TFT1.18 (DB14), TFT1.19 (DB13), TFT1.20 (DB12), TFT1.21 (DB11), TFT1.22 (DB10), TFT1.23 (DB9), TFT1.24 (DB8), TFT1.25 (DB7), TFT1.26 (DB6), TFT1.27 (DB5), TFT1.28 (DB4), TFT1.29 (DB3), TFT1.30 (DB2), TFT1.31 (DB1), TFT1.32 (DB0)
RT_CS_3V: R14.2, UTSC.5 (SDAT); also elsewhere on the board
RT_INT: R13.1, UTSC.2 (INTERRUPT); also elsewhere on the board
SCLK: R31.2, TFT1.37 (RS), UTSC.4 (SCLK); also elsewhere on the board
TFT_3V3: IC1.3 (VCC), R12.1, R14.1, R16.2, R27.2, R28.2, R29.2, R30.2, R31.1, R32.1, TFT1.7 (IM1), TFT1.8 (IM2), TFT1.9 (IM3), TFT1.40 (IOVCC), TFT1.41 (IOVCC), TFT1.42 (VCI), UTSC.6 (VCC), UTSC.9 (IN1/GPIO-1/MODE), UTSC.14 (VIO); also elsewhere on the board
TFT_CS_3V: TFT1.38 (#CS); also elsewhere on the board
TFT_DC_3V: TFT1.36 (#WR); also elsewhere on the board
TFT_RESET: IC1.2 (/RESET), R16.1, TFT1.10 (RESET)
X+: TFT1.44 (XR), UTSC.13 (X+)
X-: TFT1.46 (XL), UTSC.16 (X-)
Y+: TFT1.47 (YU), UTSC.15 (Y+)
Y-: TFT1.45 (YD), UTSC.1 (Y-)

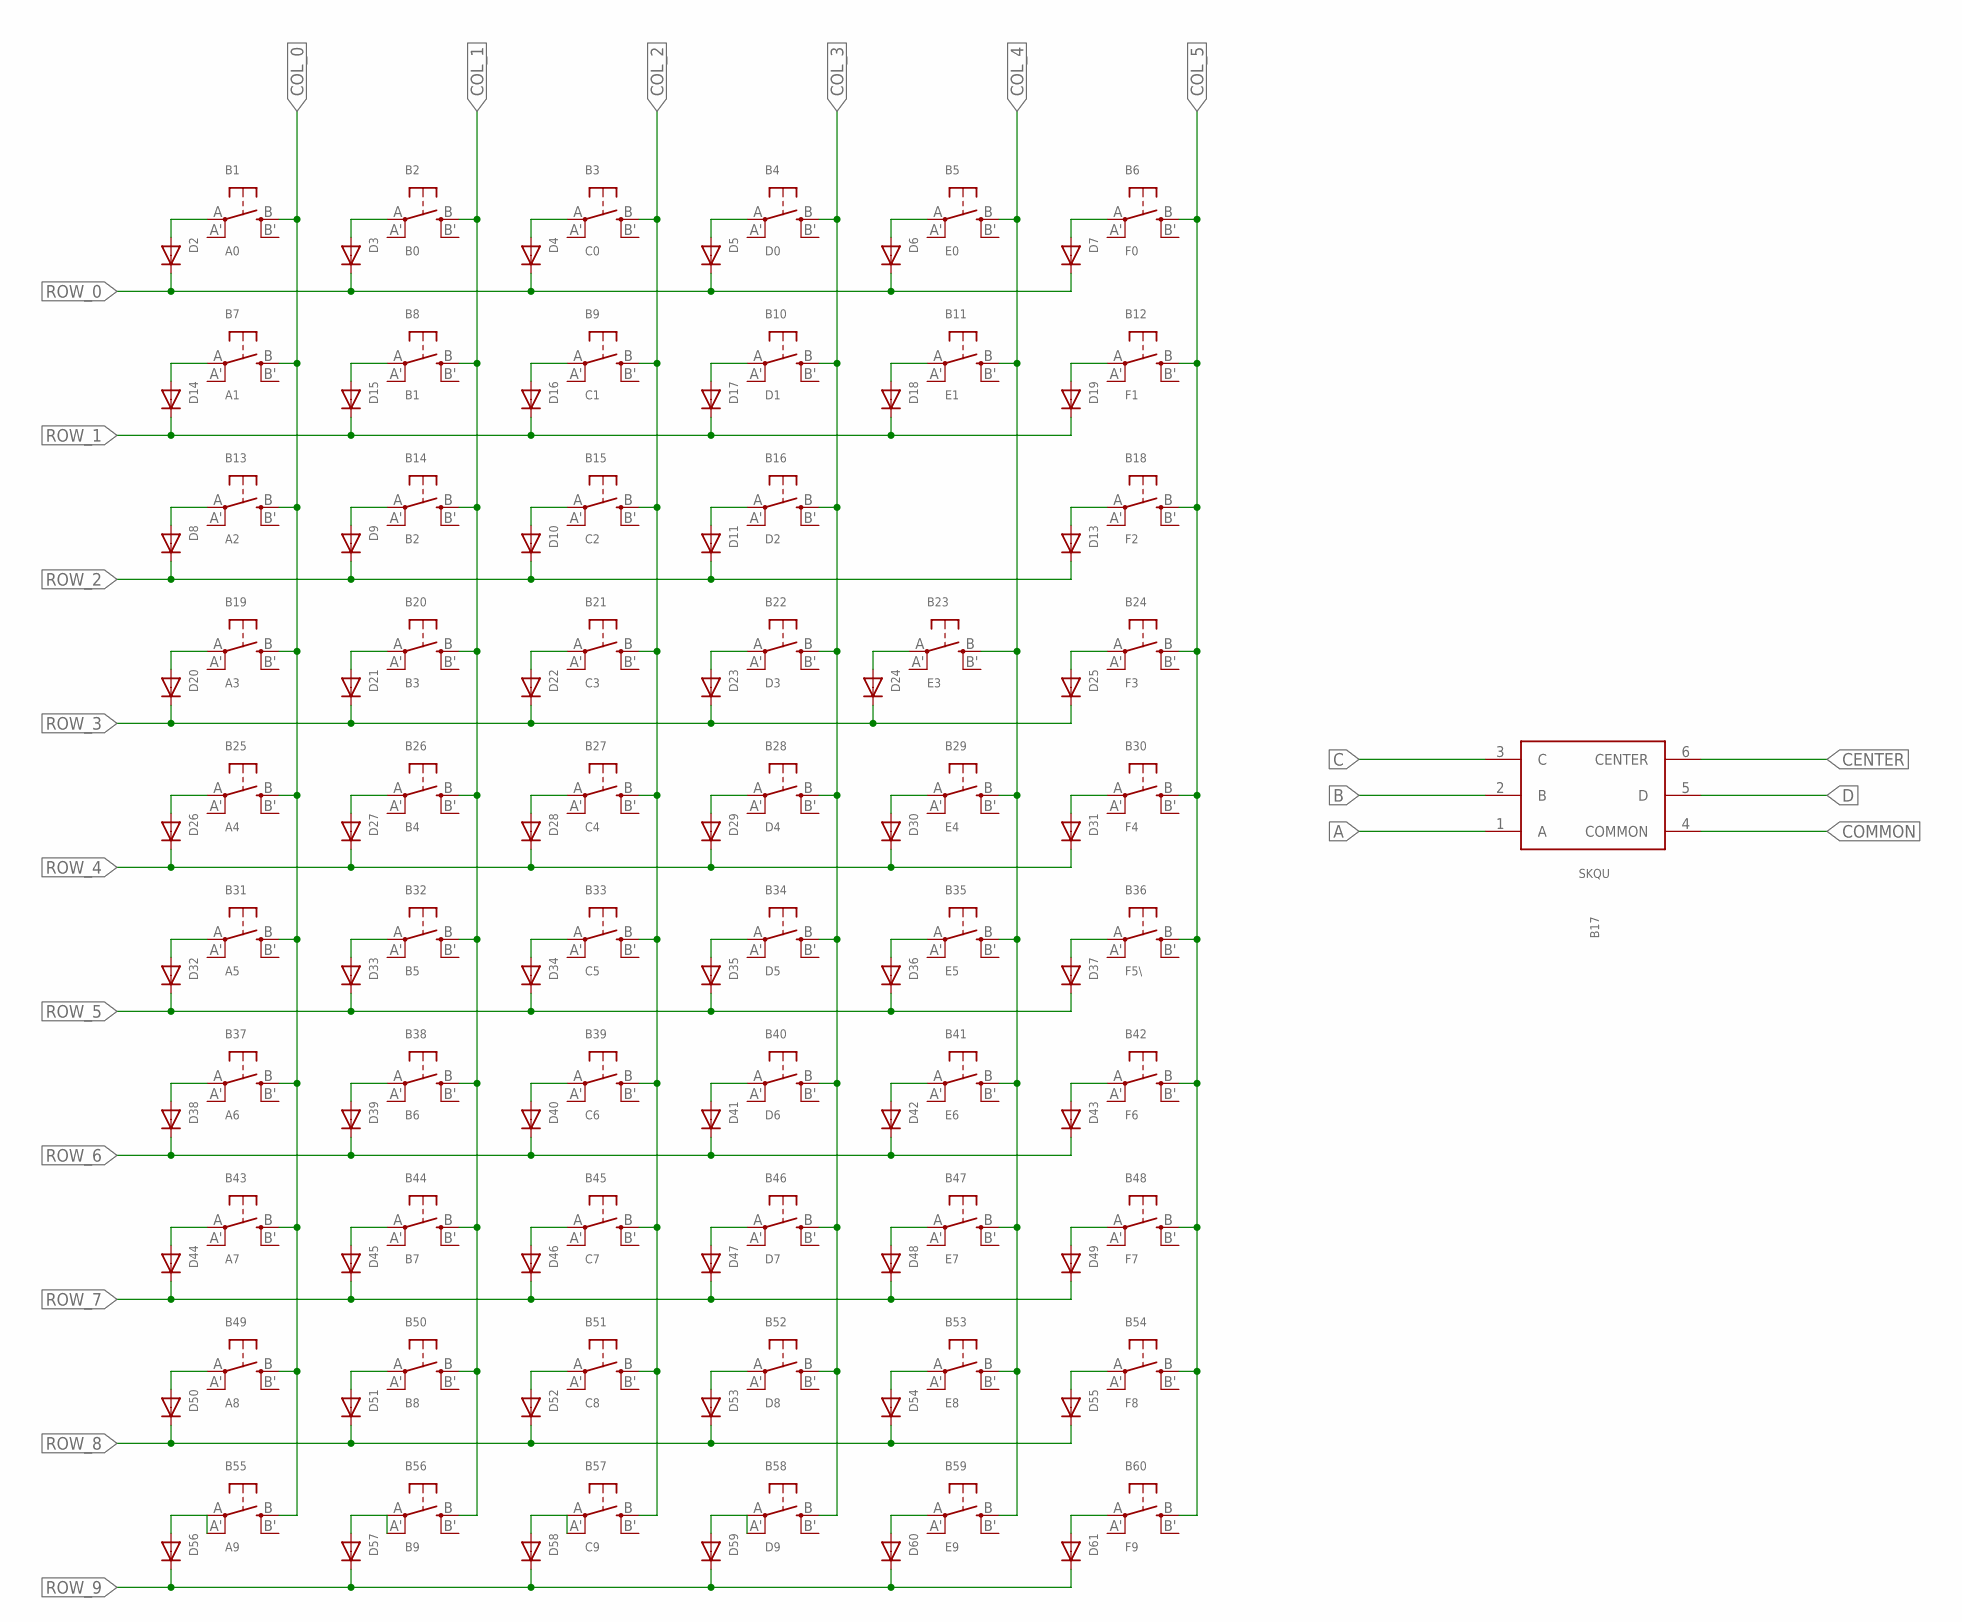
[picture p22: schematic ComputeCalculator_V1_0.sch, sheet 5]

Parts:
B1: A0; EVQ-Q2
B2: B0; EVQ-Q2
B3: C0; EVQ-Q2
B4: D0; EVQ-Q2
B5: E0; EVQ-Q2
B6: F0; EVQ-Q2
B7: A1; EVQ-Q2
B8: B1; EVQ-Q2
B9: C1; EVQ-Q2
B10: D1; EVQ-Q2
B11: E1; EVQ-Q2
B12: F1; EVQ-Q2
B13: A2; EVQ-Q2
B14: B2; EVQ-Q2
B15: C2; EVQ-Q2
B16: D2; EVQ-Q2
B17: SKQU
B18: F2; EVQ-Q2
B19: A3; EVQ-Q2
B20: B3; EVQ-Q2
B21: C3; EVQ-Q2
B22: D3; EVQ-Q2
B23: E3; EVQ-Q2
B24: F3; EVQ-Q2
B25: A4; EVQ-Q2
B26: B4; EVQ-Q2
B27: C4; EVQ-Q2
B28: D4; EVQ-Q2
B29: E4; EVQ-Q2
B30: F4; EVQ-Q2
B31: A5; EVQ-Q2
B32: B5; EVQ-Q2
B33: C5; EVQ-Q2
B34: D5; EVQ-Q2
B35: E5; EVQ-Q2
B36: F5\; EVQ-Q2
B37: A6; EVQ-Q2
B38: B6; EVQ-Q2
B39: C6; EVQ-Q2
B40: D6; EVQ-Q2
B41: E6; EVQ-Q2
B42: F6; EVQ-Q2
B43: A7; EVQ-Q2
B44: B7; EVQ-Q2
B45: C7; EVQ-Q2
B46: D7; EVQ-Q2
B47: E7; EVQ-Q2
B48: F7; EVQ-Q2
B49: A8; EVQ-Q2
B50: B8; EVQ-Q2
B51: C8; EVQ-Q2
B52: D8; EVQ-Q2
B53: E8; EVQ-Q2
B54: F8; EVQ-Q2
B55: A9; EVQ-Q2
B56: B9; EVQ-Q2
B57: C9; EVQ-Q2
B58: D9; EVQ-Q2
B59: E9; EVQ-Q2
B60: F9; EVQ-Q2
D2, D3, D4, D5, D6, D7, D8, D9, D10, D11, D13, D14, D15, D16, D17, D18, D19, D20, D21, D22, D23, D24, D25, D26, D27, D28, D29, D30, D31, D32, D33, D34, D35, D36, D37, D38, D39, D40, D41, D42, D43, D44, D45, D46, D47, D48, D49, D50, D51, D52, D53, D54, D55, D56, D57, D58, D59, D60, D61: DIODESMA; SMADIODE

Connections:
A: B17.1 (A); also elsewhere on the board
B: B17.2 (B); also elsewhere on the board
C: B17.3 (C); also elsewhere on the board
CENTER: B17.6 (CENTER); also elsewhere on the board
COL_0: B1.B (S), B7.B (S), B13.B (S), B19.B (S), B25.B (S), B31.B (S), B37.B (S), B43.B (S), B49.B (S), B55.B (S); also elsewhere on the board
COL_1: B2.B (S), B8.B (S), B14.B (S), B20.B (S), B26.B (S), B32.B (S), B38.B (S), B44.B (S), B50.B (S), B56.B (S); also elsewhere on the board
COL_2: B3.B (S), B9.B (S), B15.B (S), B21.B (S), B27.B (S), B33.B (S), B39.B (S), B45.B (S), B51.B (S), B57.B (S); also elsewhere on the board
COL_3: B4.B (S), B10.B (S), B16.B (S), B22.B (S), B28.B (S), B34.B (S), B40.B (S), B46.B (S), B52.B (S), B58.B (S); also elsewhere on the board
COL_4: B5.B (S), B11.B (S), B23.B (S), B29.B (S), B35.B (S), B41.B (S), B47.B (S), B53.B (S), B59.B (S); also elsewhere on the board
COL_5: B6.B (S), B12.B (S), B18.B (S), B24.B (S), B30.B (S), B36.B (S), B42.B (S), B48.B (S), B54.B (S), B60.B (S); also elsewhere on the board
COMMON: B17.4 (COMMON); also elsewhere on the board
D: B17.5 (D); also elsewhere on the board
unnamed: B6.A, D7.A
unnamed: B2.A, D3.A
unnamed: B3.A, D4.A
unnamed: B1.A, D2.A
unnamed: B4.A, D5.A
unnamed: B5.A, D6.A
unnamed: B13.A, D8.A
unnamed: B18.A, D13.A
unnamed: B14.A, D9.A
unnamed: B15.A, D10.A
unnamed: B16.A, D11.A
unnamed: B23.A, D24.A
unnamed: B7.A, D14.A
unnamed: B12.A, D19.A
unnamed: B8.A, D15.A
unnamed: B9.A, D16.A
unnamed: B10.A, D17.A
unnamed: B11.A, D18.A
unnamed: B19.A, D20.A
unnamed: B24.A, D25.A
unnamed: B20.A, D21.A
unnamed: B21.A, D22.A
unnamed: B22.A, D23.A
unnamed: B25.A, D26.A
unnamed: B30.A, D31.A
unnamed: B26.A, D27.A
unnamed: B27.A, D28.A
unnamed: B28.A, D29.A
unnamed: B29.A, D30.A
unnamed: B31.A, D32.A
unnamed: B36.A, D37.A
unnamed: B32.A, D33.A
unnamed: B33.A, D34.A
unnamed: B34.A, D35.A
unnamed: B35.A, D36.A
unnamed: B37.A, D38.A
unnamed: B42.A, D43.A
unnamed: B38.A, D39.A
unnamed: B39.A, D40.A
unnamed: B40.A, D41.A
unnamed: B41.A, D42.A
unnamed: B43.A, D44.A
unnamed: B48.A, D49.A
unnamed: B44.A, D45.A
unnamed: B45.A, D46.A
unnamed: B46.A, D47.A
unnamed: B47.A, D48.A
unnamed: B49.A, D50.A
unnamed: B54.A, D55.A
unnamed: B50.A, D51.A
unnamed: B51.A, D52.A
unnamed: B52.A, D53.A
unnamed: B53.A, D54.A
unnamed: B55.A, B55.A' (P1), D56.A
unnamed: B60.A, D61.A
unnamed: B56.A, B56.A' (P1), D57.A
unnamed: B57.A, B57.A' (P1), D58.A
unnamed: B58.A, B58.A' (P1), D59.A
unnamed: B59.A, D60.A
ROW_0: D2.C, D3.C, D4.C, D5.C, D6.C, D7.C; also elsewhere on the board
ROW_1: D14.C, D15.C, D16.C, D17.C, D18.C, D19.C; also elsewhere on the board
ROW_2: D8.C, D9.C, D10.C, D11.C, D13.C; also elsewhere on the board
ROW_3: D20.C, D21.C, D22.C, D23.C, D24.C, D25.C; also elsewhere on the board
ROW_4: D26.C, D27.C, D28.C, D29.C, D30.C, D31.C; also elsewhere on the board
ROW_5: D32.C, D33.C, D34.C, D35.C, D36.C, D37.C; also elsewhere on the board
ROW_6: D38.C, D39.C, D40.C, D41.C, D42.C, D43.C; also elsewhere on the board
ROW_7: D44.C, D45.C, D46.C, D47.C, D48.C, D49.C; also elsewhere on the board
ROW_8: D50.C, D51.C, D52.C, D53.C, D54.C, D55.C; also elsewhere on the board
ROW_9: D56.C, D57.C, D58.C, D59.C, D60.C, D61.C; also elsewhere on the board

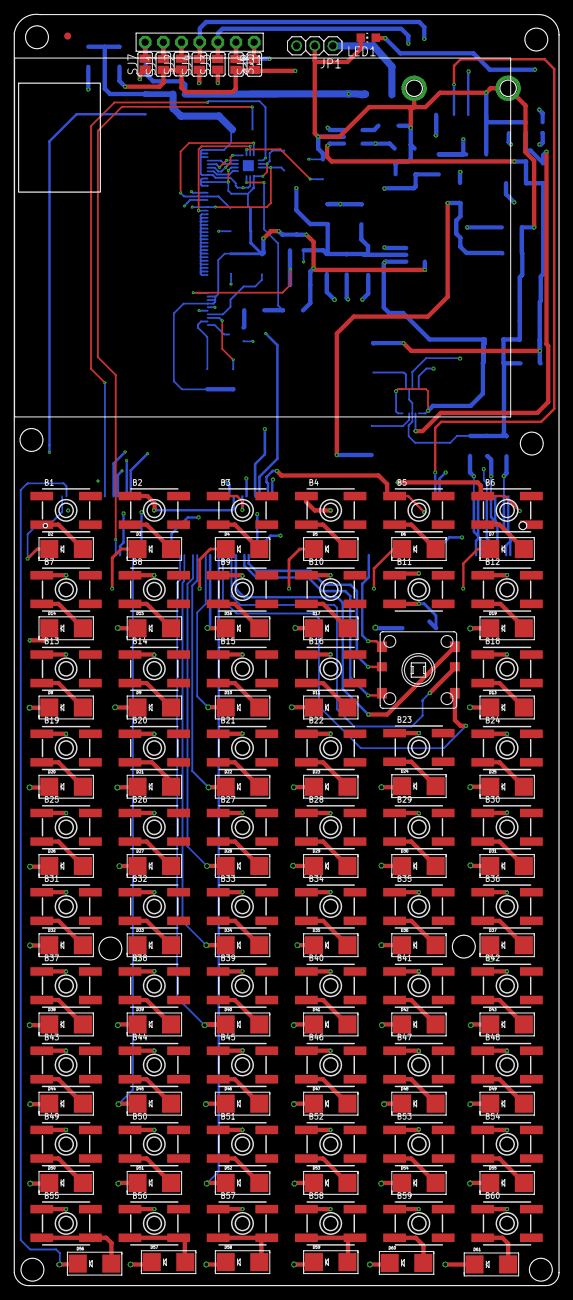
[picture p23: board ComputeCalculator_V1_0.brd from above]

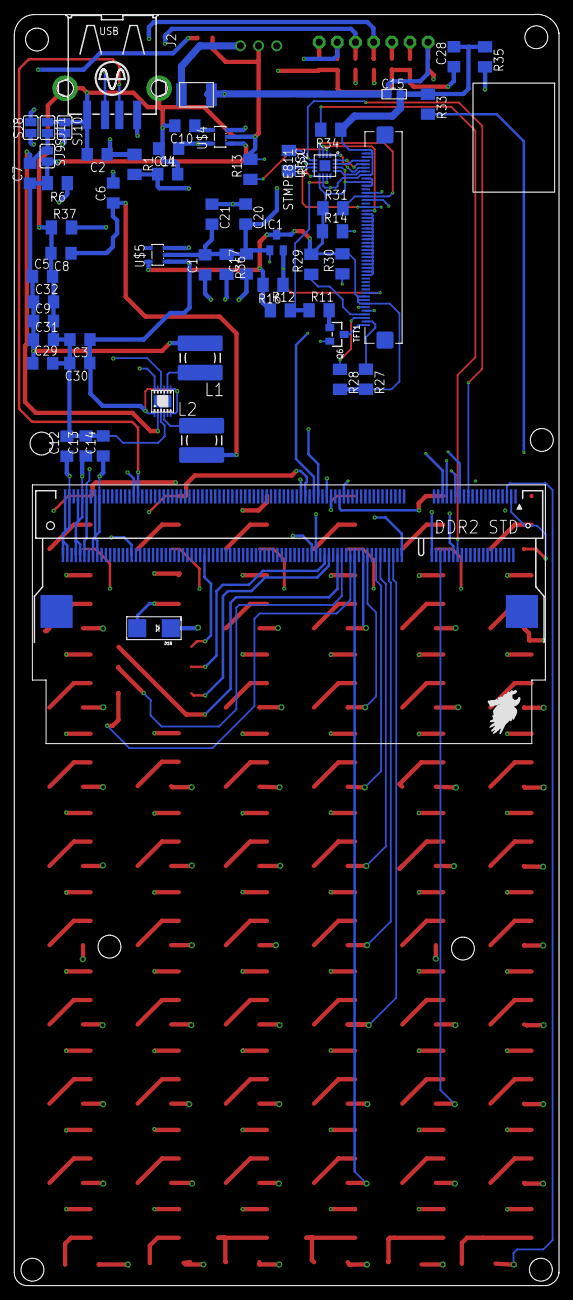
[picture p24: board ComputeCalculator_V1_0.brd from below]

Board: 4 copper layers, 76.2 x 177.9 mm, 187 parts (57 on the bottom side), 129 nets.

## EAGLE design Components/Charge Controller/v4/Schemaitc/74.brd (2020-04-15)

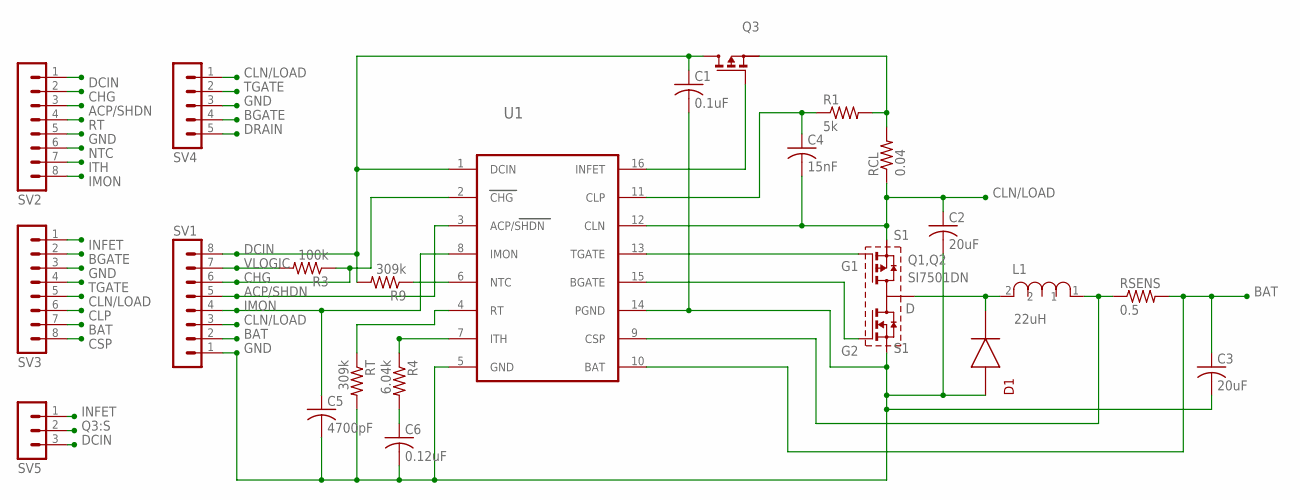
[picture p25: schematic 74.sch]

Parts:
C1: 0.1uF; C1210
C2, C3: 20uF; C1210
C4: 15nF; C1210
C5: 4700pF; C1210
C6: 0.12uF; C1210
D1: DIODE
L1: 22uH; POWERINDUCTOR
Q1,Q2: SI7501DN; POWERPAK
Q3: MOSFET; SOT-23
R1: 5k; R1206
R3: 100k; R1206
R4: 6.04k; R1206
R9: 309k; R1206
RCL: 0.04; R1206
RSENS: 0.5; 0612/1632
RT: 309k; R1206
SV1, SV2, SV3: MA08-1
SV4: MA05-1
SV5: MA03-1
U1: LTC6004; SSOP-16

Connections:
ACP/SHDN: SV1.5, SV2.3, U1.3 (ACP/SHDN)
BAT: C3.1, RSENS.2, SV1.2, SV3.7, U1.10 (BAT)
BGATE: Q1,Q2.G2, SV3.2, SV4.4, U1.15 (BGATE)
CHG: R3.1, SV1.6, SV2.2, U1.2 (CHG)
CLN/LOAD: C2.1, C4.2, Q1,Q2.S1, RCL.1, SV1.3, SV3.5, SV4.1, U1.12 (CLN)
CLP: C4.1, R1.1, SV3.6, U1.11 (CLP)
CSP: L1.1, RSENS.1, SV3.8, U1.9 (CSP)
DCIN: C1.1, Q3.DRAIN (D), R9.2, SV1.8, SV2.1, SV5.3, U1.1 (DCIN)
DRAIN: D1.P$2 (2), L1.2, Q1,Q2.D, SV4.5
GND: C1.2, C2.2, C3.2, C5.2, C6.2, D1.P$1 (1), Q1,Q2.S2, RT.2, SV1.1, SV2.5, SV3.3, SV4.3, U1.5 (GND), U1.14 (PGND)
IMON: C5.1, SV1.4, SV2.8, U1.8 (IMON)
INFET: Q3.GATE (G), SV3.1, SV5.1, U1.16 (INFET)
ITH: R4.1, SV2.7, U1.7 (ITH)
unnamed: C6.1, R4.2
NTC: R9.1, SV2.6, U1.6 (NTC)
Q3:S: Q3.SOURCE (S), R1.2, RCL.2, SV5.2
RT: RT.1, SV2.4, U1.4 (RT)
TGATE: Q1,Q2.G1, SV3.4, SV4.2, U1.13 (TGATE)
VLOGIC: R3.2, SV1.7

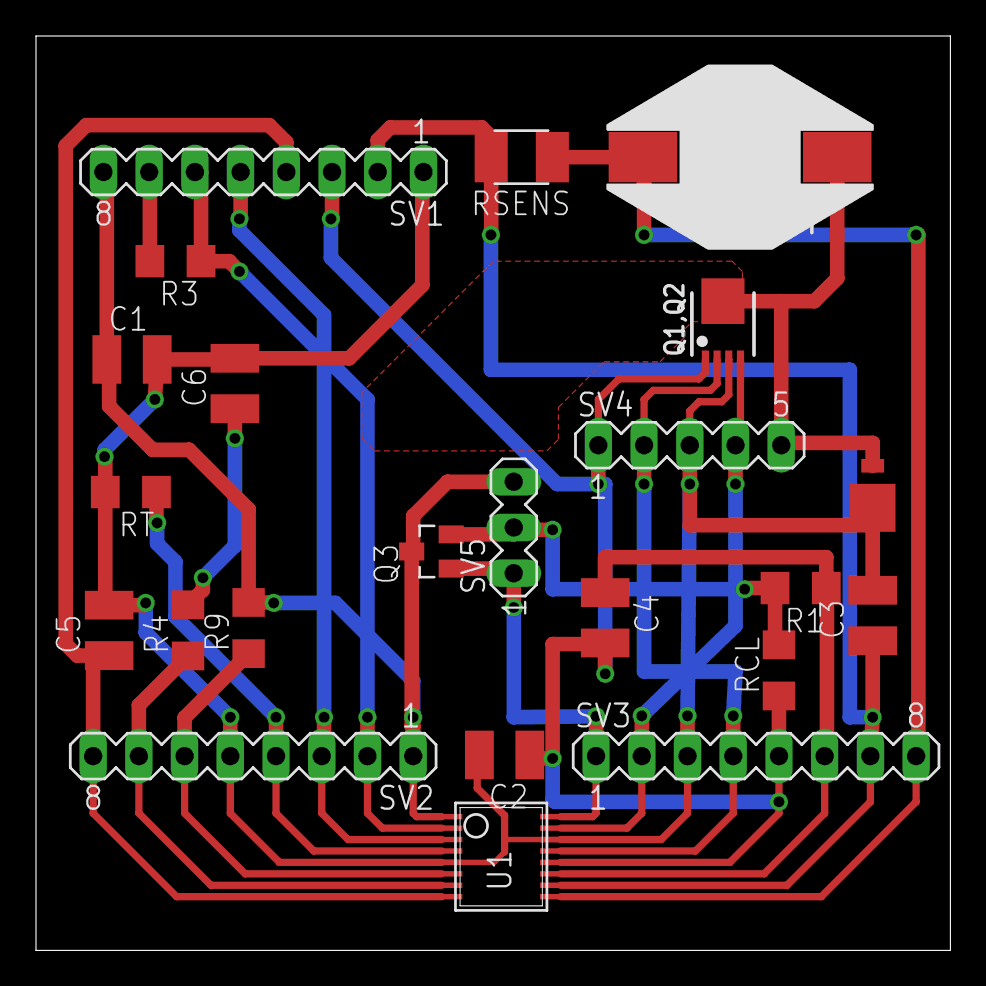
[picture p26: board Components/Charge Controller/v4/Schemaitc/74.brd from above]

Board: 2 copper layers, 50.8 x 50.8 mm, 23 parts (0 on the bottom side), 19 nets.

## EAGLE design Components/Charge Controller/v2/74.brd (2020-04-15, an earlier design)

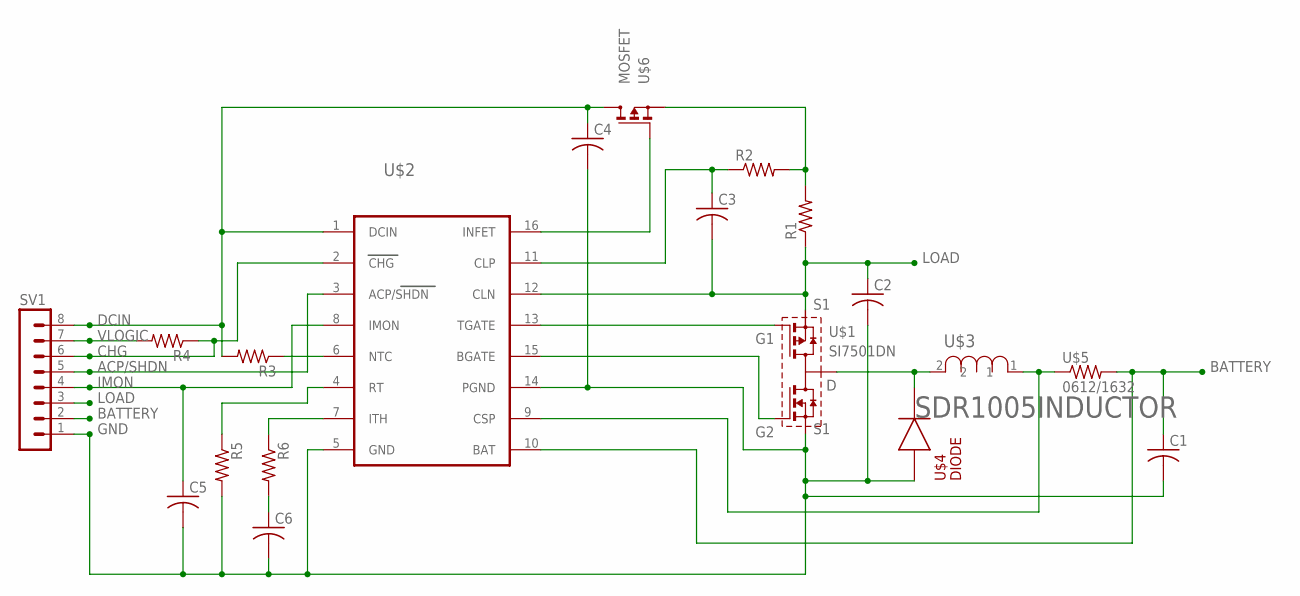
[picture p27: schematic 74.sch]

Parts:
C1, C2, C3, C4, C5, C6: C-USC1210; C1210
R1, R2, R3, R4, R5, R6: R-US_R1206; R1206
SV1: MA08-1
U$1: SI7501DN; POWERPAK
U$2: LTC6004; SSOP-16
U$3: SDR1005INDUCTOR; POWERINDUCTOR
U$4: DIODE
U$5: 0612/1632
U$6: MOSFET; SOT-23

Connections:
ACP/SHDN: SV1.5, U$2.3 (ACP/SHDN)
BATTERY: C1.1, SV1.2, U$2.10 (BAT), U$5.2
CHG: R4.1, SV1.6, U$2.2 (CHG)
DCIN: C4.1, R3.2, SV1.8, U$2.1 (DCIN), U$6.DRAIN (D)
GND: C1.2, C2.2, C4.2, C5.2, C6.2, R5.2, SV1.1, U$1.S2, U$2.5 (GND), U$2.14 (PGND), U$4.P$1 (1)
IMON: C5.1, SV1.4, U$2.8 (IMON)
LOAD: C2.1, C3.2, R1.1, SV1.3, U$1.S1, U$2.12 (CLN)
unnamed: U$1.G1, U$2.13 (TGATE)
unnamed: U$1.G2, U$2.15 (BGATE)
unnamed: U$1.D, U$3.2, U$4.P$2 (2)
unnamed: U$2.9 (CSP), U$3.1, U$5.1
unnamed: C3.1, R2.1, U$2.11 (CLP)
unnamed: R1.2, R2.2, U$6.SOURCE (S)
unnamed: U$2.16 (INFET), U$6.GATE (G)
unnamed: R6.1, U$2.7 (ITH)
unnamed: R3.1, U$2.6 (NTC)
unnamed: C6.1, R6.2
unnamed: R5.1, U$2.4 (RT)
VLOGIC: R4.2, SV1.7

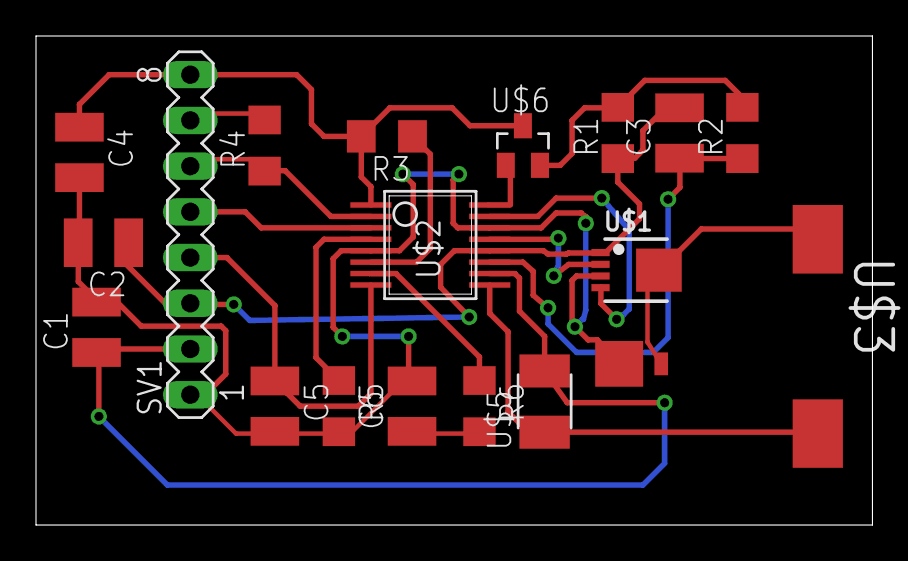
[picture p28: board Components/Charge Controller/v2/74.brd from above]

Board: 2 copper layers, 46.5 x 27.2 mm, 19 parts (0 on the bottom side), 19 nets.

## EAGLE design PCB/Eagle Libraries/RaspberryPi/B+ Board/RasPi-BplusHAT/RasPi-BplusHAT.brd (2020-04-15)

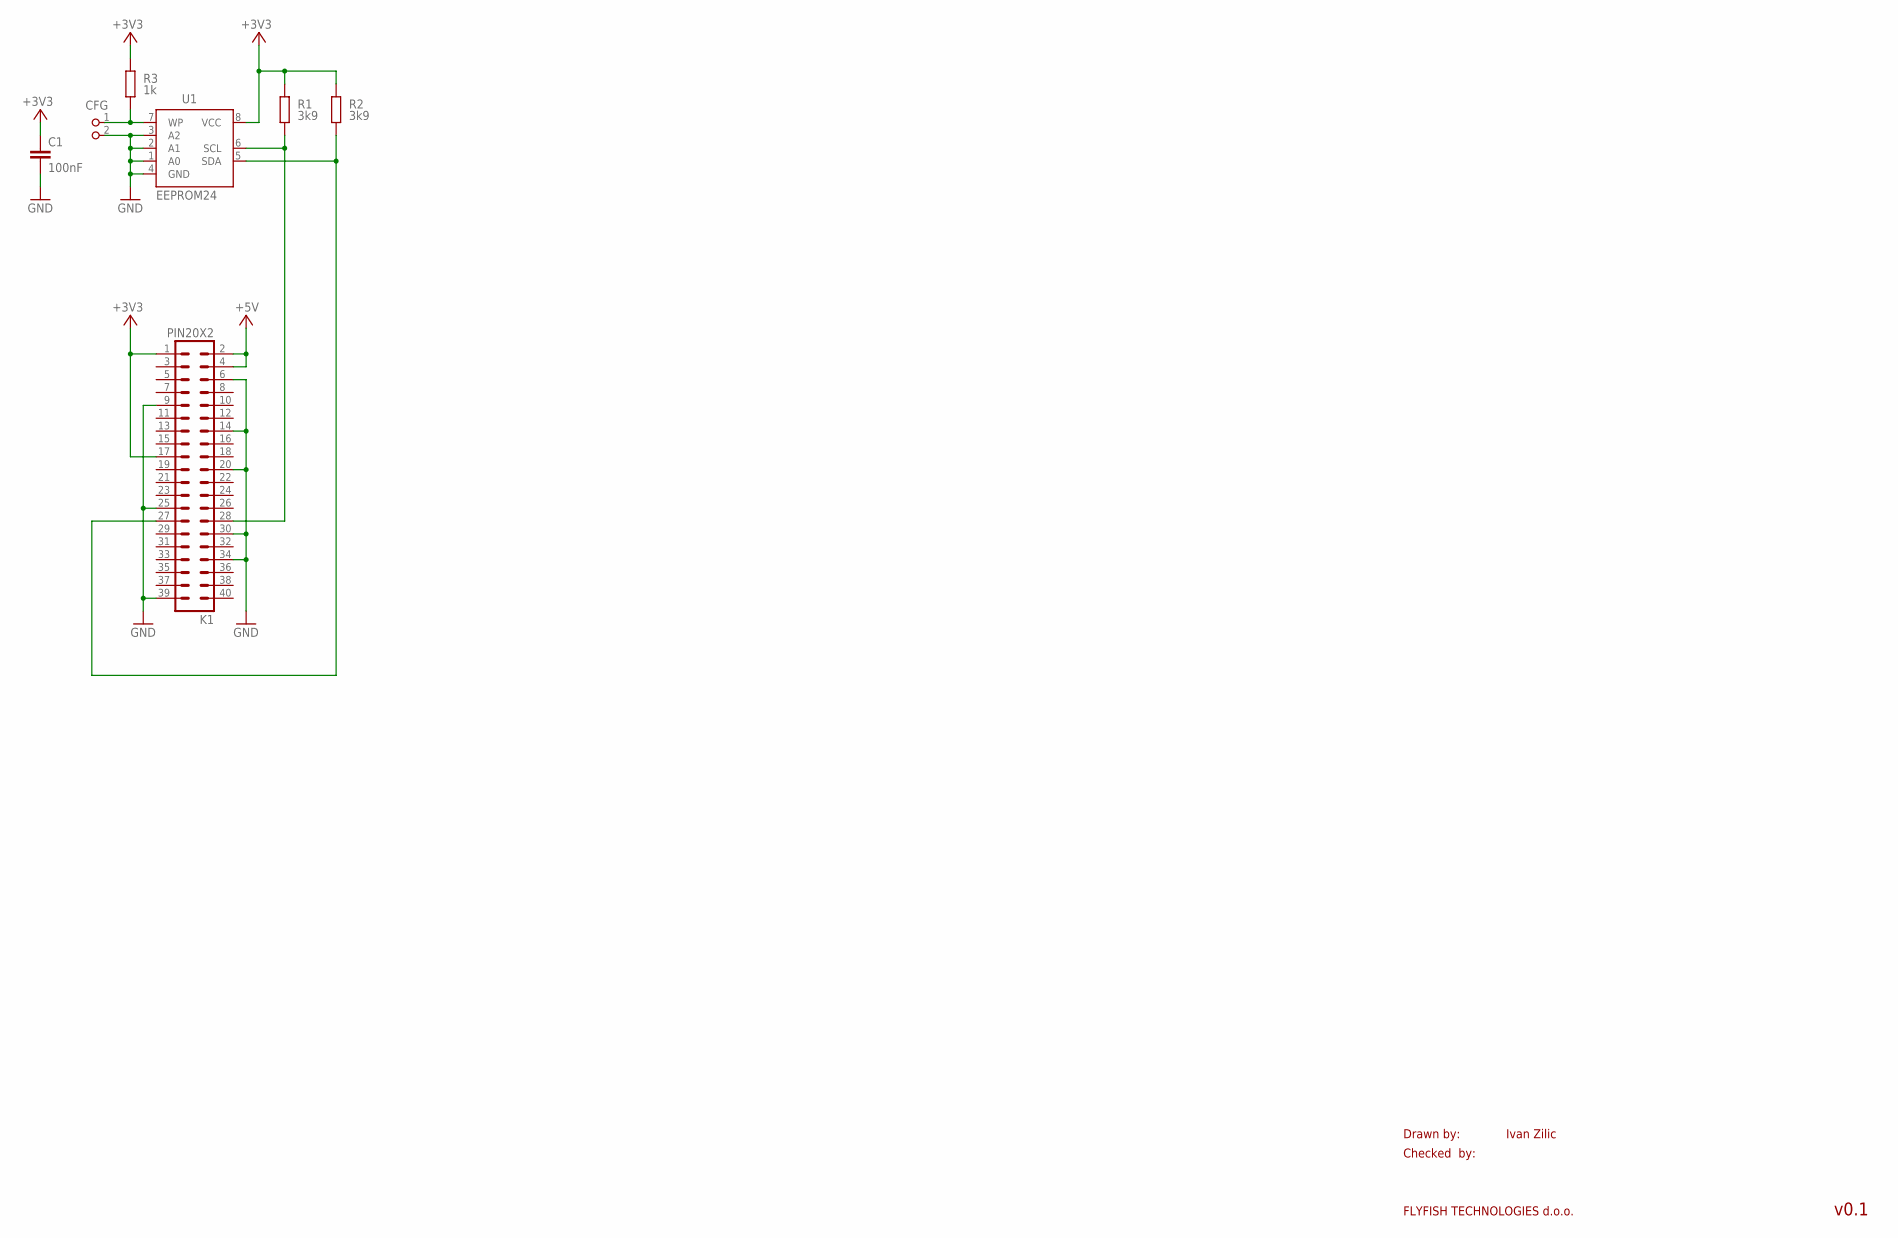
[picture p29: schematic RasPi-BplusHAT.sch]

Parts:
C1: 100nF; C0805K
CFG: PIN2_100; PIN_W_2
K1: PIN20X2; PIN_20X2
R1, R2: 3k9; M0805; TOLERANCE 5%
R3: 1k; M0805; TOLERANCE 5%
U1: EEPROM24; SOIC8

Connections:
+3V3: C1.1, K1.1, K1.17, R1.2, R2.2, R3.2, U1.8 (VCC)
+5V: K1.2, K1.4
GND: C1.2, CFG.2, K1.6, K1.9, K1.14, K1.20, K1.25, K1.30, K1.34, K1.39, U1.1 (A0), U1.2 (A1), U1.3 (A2), U1.4 (GND)
unnamed: K1.28, R1.1, U1.6 (SCL)
unnamed: K1.27, R2.1, U1.5 (SDA)
unnamed: CFG.1, R3.1, U1.7 (WP)

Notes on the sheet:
Drawn by:
Checked by:
FLYFISH TECHNOLOGIES d.o.o.
Ivan Zilic
v0.1

Board: 2 copper layers, 7 parts (0 on the bottom side), 6 nets, no tracks yet.

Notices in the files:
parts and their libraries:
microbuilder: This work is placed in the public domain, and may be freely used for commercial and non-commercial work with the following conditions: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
